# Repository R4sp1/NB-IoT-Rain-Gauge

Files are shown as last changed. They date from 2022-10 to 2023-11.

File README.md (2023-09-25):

# Návrh přesného srážkoměru s možností real-time odečtu

## Zadání
V teoretické části prostudujte principy měření objemu srážek. Prostudujte současné možnosti využití LPWAN sítí pro přenos naměřených hodnot. Na základě průzkumu dostupných řešení vyberte vhodnou metodu a měřicí modul pro přesné stanovení míry srážek. Současně vyberte vhodné komunikační řešení, které umožní real-time přenos naměřených hodnot. Výstupem semestrální práce je návrh a sestrojení zařízení pro přesné měření srážek s možností odesílání naměřených hodnot na server v reálném čase.

[Odkaz na práci](https://www.vut.cz/studenti/zav-prace/detail/151055 "Záverečné práce na VUT")

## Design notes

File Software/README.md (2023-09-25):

# Software folder
This folder contains all software:

* Firmware: contains two versions:
    * WiFi - using ESP32 onboard WiFi,
    * NB - using Quectel BC660K communication chip.
* Server-side: contains NodeRED flow which processes the data and sends them to the external InfluxDB database.

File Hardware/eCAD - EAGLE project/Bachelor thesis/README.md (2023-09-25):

# eCAD files
This subfolder contains project files from EAGLE eCAD software. The main design is located in folder: [Main board](https://github.com/R4sp1/NB-IoT-Rain-Gauge/tree/main/Hardware/eCAD%20-%20EAGLE%20project/Bachelor%20thesis/Main%20board).

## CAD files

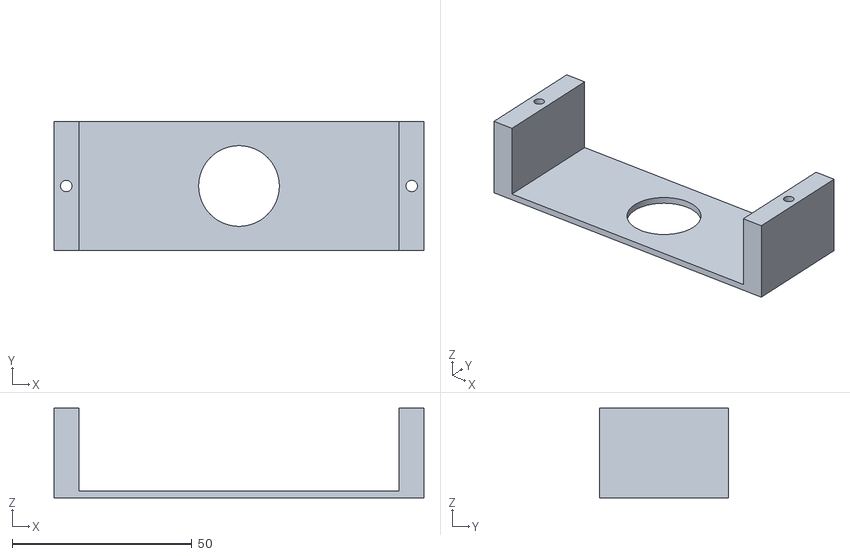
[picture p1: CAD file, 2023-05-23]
Hardware/Manufacture files/STL/Box/Cover.stl
102.8 x 35.8 x 25.0

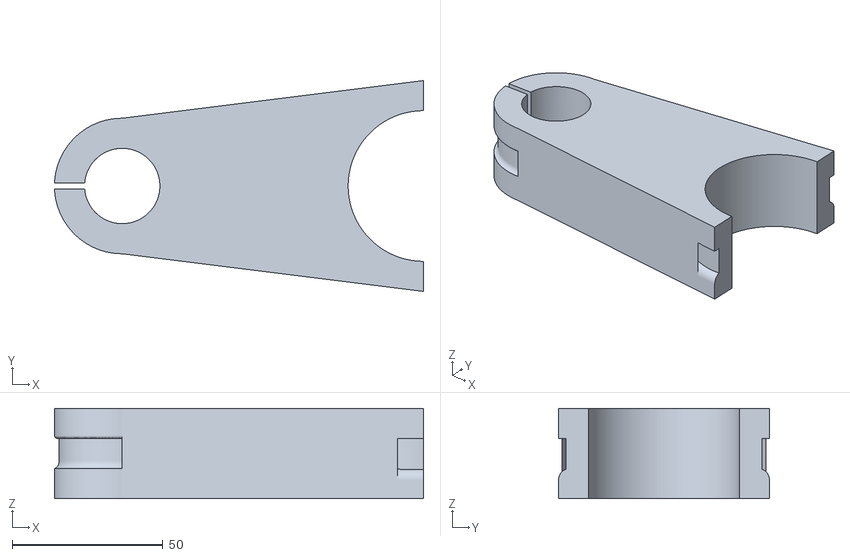
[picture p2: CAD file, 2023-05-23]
Hardware/Manufacture files/STL/Mount/Pole mount (50mm).stl
122.5 x 70.0 x 30.0

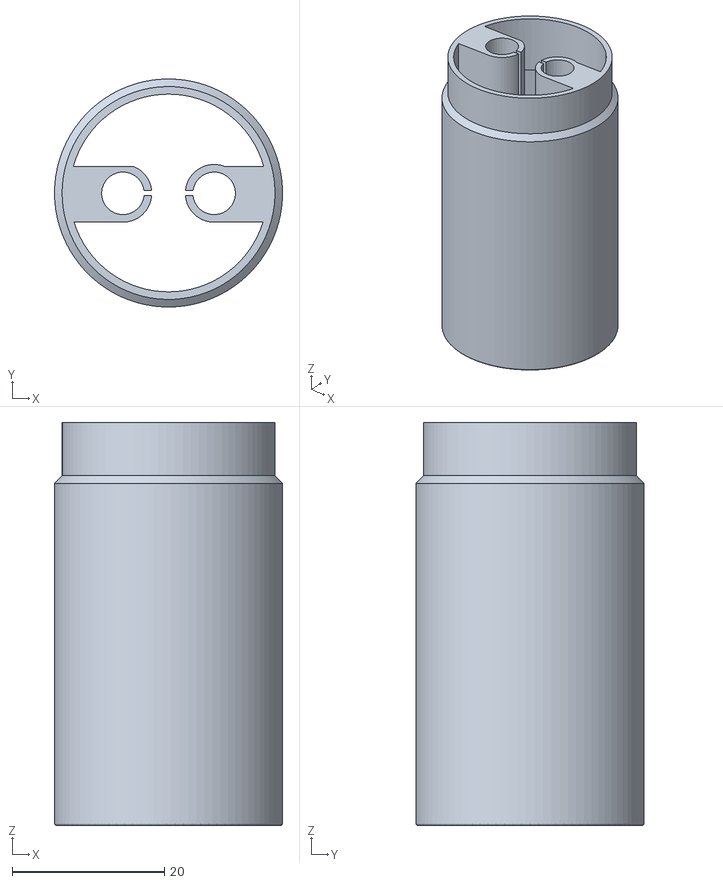
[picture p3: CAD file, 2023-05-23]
Hardware/Manufacture files/STL/Radiation shield/Bottom fan tube (temp sensor holders).stl
30.0 x 30.0 x 53.0

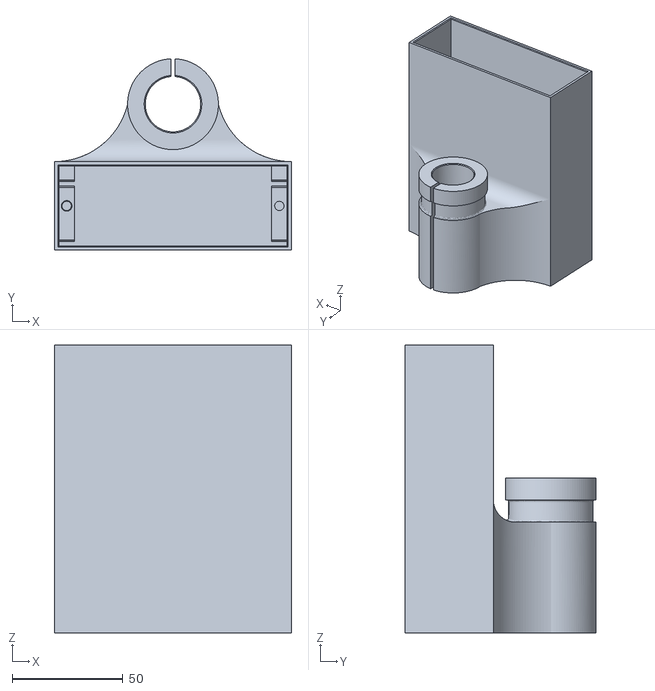
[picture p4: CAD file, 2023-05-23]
Hardware/Manufacture files/STL/Box/Box.stl
107.0 x 86.4 x 130.0

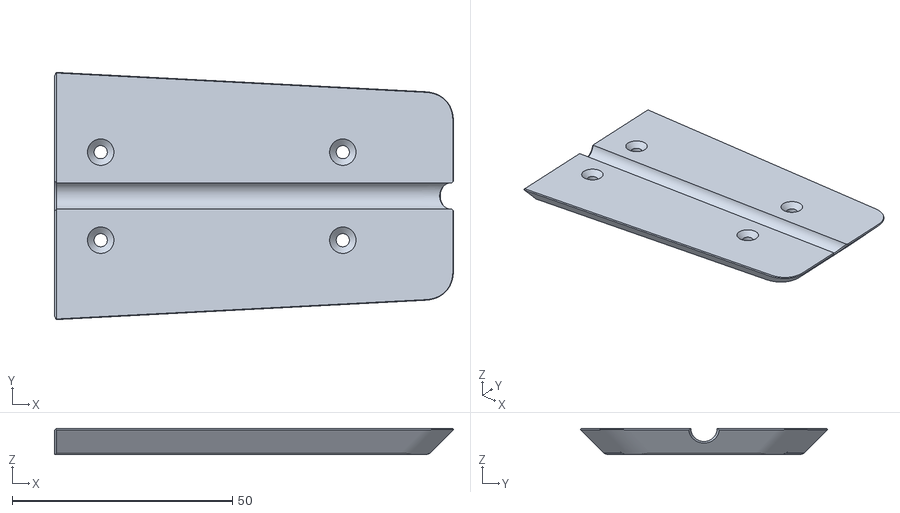
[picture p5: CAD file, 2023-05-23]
Hardware/Manufacture files/STL/Radiation shield/PV panel holder 2.stl
90.6 x 56.2 x 6.00

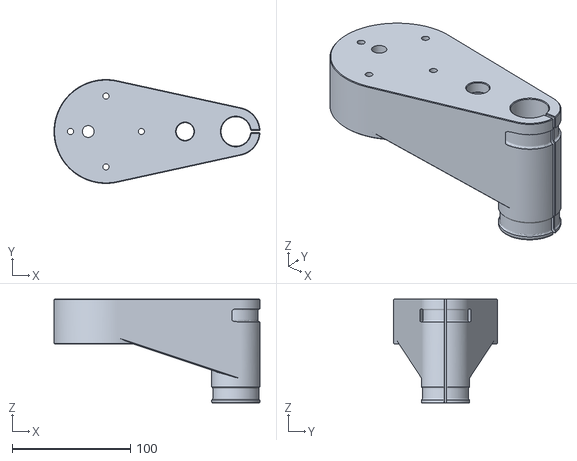
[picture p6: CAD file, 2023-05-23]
Hardware/Manufacture files/STL/Radiation shield/25mm pole mount.stl
174.5 x 88.0 x 88.0

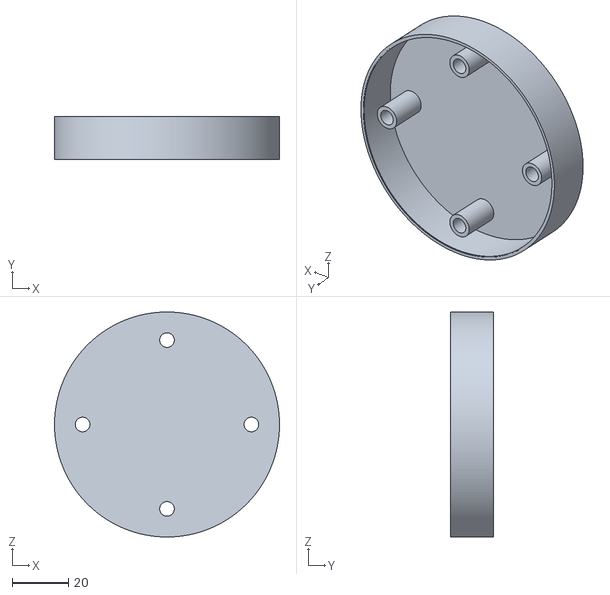
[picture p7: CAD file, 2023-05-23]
Hardware/Manufacture files/STL/Radiation shield/Fan cover.stl
80.0 x 15.2 x 80.0

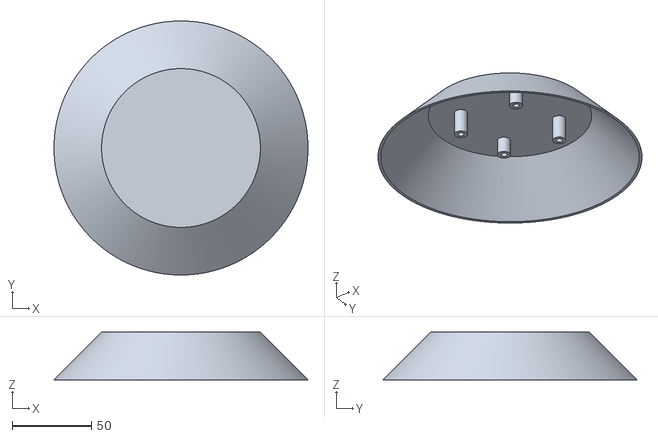
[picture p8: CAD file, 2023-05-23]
Hardware/Manufacture files/STL/Radiation shield/Top cover.stl
160.0 x 160.0 x 30.0

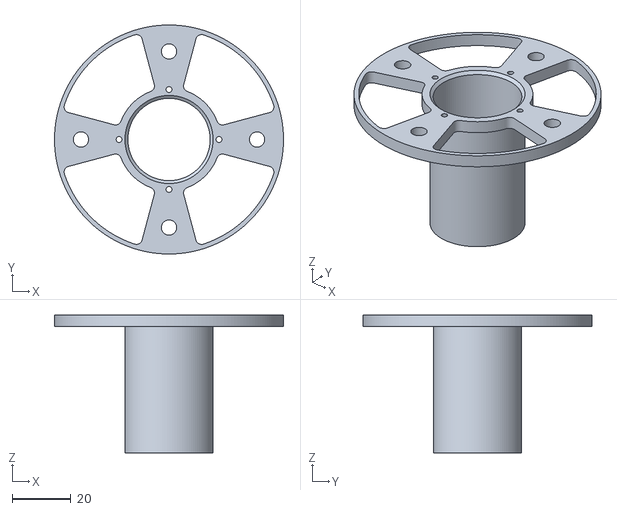
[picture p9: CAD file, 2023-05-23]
Hardware/Manufacture files/STL/Radiation shield/Top fan tube.stl
78.0 x 78.0 x 47.0

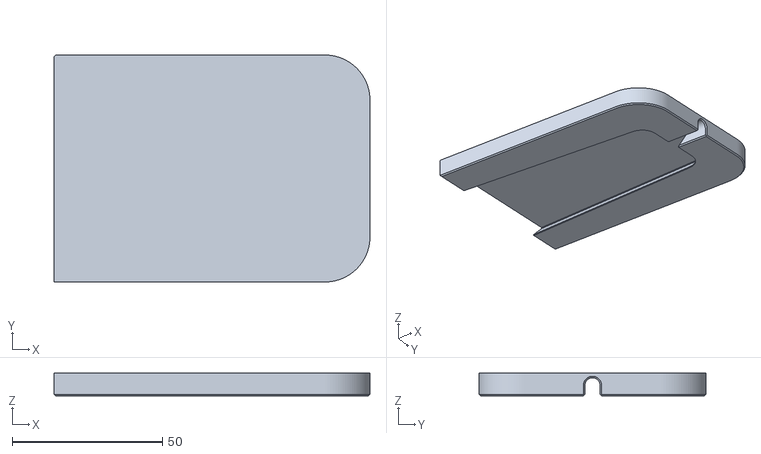
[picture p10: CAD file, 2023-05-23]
Hardware/Manufacture files/STL/Radiation shield/PV panel holder 3.stl
105.0 x 75.4 x 7.50

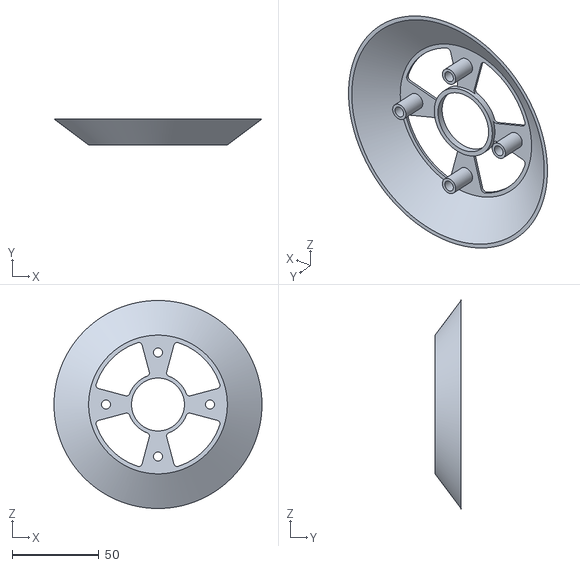
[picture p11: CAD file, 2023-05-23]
Hardware/Manufacture files/STL/Radiation shield/Shield.stl
120.0 x 15.0 x 120.0

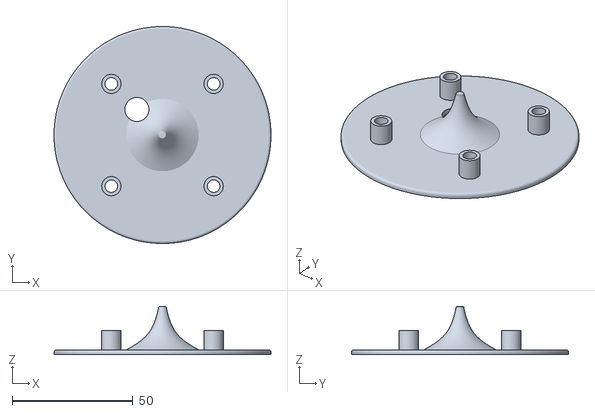
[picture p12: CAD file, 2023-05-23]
Hardware/Manufacture files/STL/Radiation shield/Bottom cover.stl
90.0 x 90.0 x 20.0

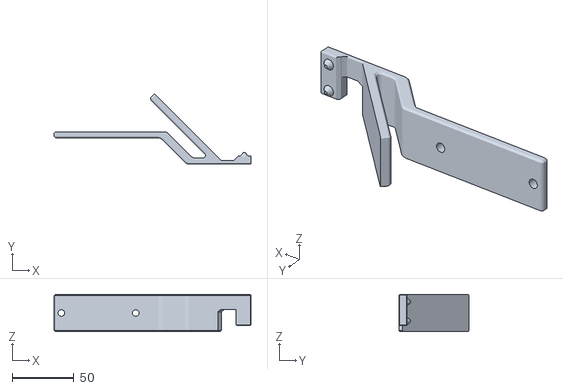
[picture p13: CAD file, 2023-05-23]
Hardware/Manufacture files/STL/Radiation shield/PV panel holder 1.stl
159.1 x 56.9 x 30.0

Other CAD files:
Hardware/CAD - Fusion360 3D models/Electronics box/Cover.f3d
Hardware/CAD - Fusion360 3D models/Electronics box/Electronics box.f3d
Hardware/CAD - Fusion360 3D models/Mount/Pole mount (50mm).f3d
Hardware/CAD - Fusion360 3D models/Radiation shield/Bottom cover.f3d
Hardware/CAD - Fusion360 3D models/Radiation shield/Bottom fan tube (temp sensor holders).f3d
Hardware/CAD - Fusion360 3D models/Radiation shield/Fan cover.f3d
Hardware/CAD - Fusion360 3D models/Radiation shield/Mount.f3d
Hardware/CAD - Fusion360 3D models/Radiation shield/PV panel holder 1.f3d
Hardware/CAD - Fusion360 3D models/Radiation shield/PV panel holder 2.f3d
Hardware/CAD - Fusion360 3D models/Radiation shield/PV panel holder 3.f3d
Hardware/CAD - Fusion360 3D models/Radiation shield/Shield.f3d
Hardware/CAD - Fusion360 3D models/Radiation shield/Top cover.f3d
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

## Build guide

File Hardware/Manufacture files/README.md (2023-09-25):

# Manufacture files
This subfolder contains files:

* ready to be printed as they are on Prusa i3 MK3S+,
* or files that can be imported into any slicer as .stl files.

RAW models in Fusion360 format .f3d can be found in [CAD - Fusion360 3D models](https://github.com/R4sp1/NB-IoT-Rain-Gauge/tree/main/Hardware/CAD%20-%20Fusion360%203D%20models) folder.

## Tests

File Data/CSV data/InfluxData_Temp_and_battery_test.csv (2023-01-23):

#group | false | false | true | true | false | false | true | true
#datatype | string | long | dateTime:RFC3339 | dateTime:RFC3339 | dateTime:RFC3339 | double | string | string
#default | last
 | result | table | _start | _stop | _time | _value | _field | _measurement
 |  | 0 | 2022-12-25T16:00:00Z | 2023-01-09T13:00:00Z | 2022-12-25T16:08:30Z | 6.125 | Temp | NBtest
 |  | 0 | 2022-12-25T16:00:00Z | 2023-01-09T13:00:00Z | 2022-12-25T17:08:00Z | 4.1875 | Temp | NBtest
 |  | 0 | 2022-12-25T16:00:00Z | 2023-01-09T13:00:00Z | 2022-12-25T18:07:30Z | 3.375 | Temp | NBtest
 |  | 0 | 2022-12-25T16:00:00Z | 2023-01-09T13:00:00Z | 2022-12-25T19:07:00Z | 3.25 | Temp | NBtest
 |  | 0 | 2022-12-25T16:00:00Z | 2023-01-09T13:00:00Z | 2022-12-25T20:06:30Z | 3.5 | Temp | NBtest
 |  | 0 | 2022-12-25T16:00:00Z | 2023-01-09T13:00:00Z | 2022-12-25T21:06:00Z | 4 | Temp | NBtest
 |  | 0 | 2022-12-25T16:00:00Z | 2023-01-09T13:00:00Z | 2022-12-25T22:05:30Z | 3.3125 | Temp | NBtest
 |  | 0 | 2022-12-25T16:00:00Z | 2023-01-09T13:00:00Z | 2022-12-25T23:05:00Z | 3.125 | Temp | NBtest
 |  | 0 | 2022-12-25T16:00:00Z | 2023-01-09T13:00:00Z | 2022-12-26T00:04:30Z | 2.625 | Temp | NBtest
 |  | 0 | 2022-12-25T16:00:00Z | 2023-01-09T13:00:00Z | 2022-12-26T01:04:00Z | 6.5625 | Temp | NBtest
 |  | 0 | 2022-12-25T16:00:00Z | 2023-01-09T13:00:00Z | 2022-12-26T02:03:30Z | 5.375 | Temp | NBtest
 |  | 0 | 2022-12-25T16:00:00Z | 2023-01-09T13:00:00Z | 2022-12-26T03:03:00Z | 4.625 | Temp | NBtest
 |  | 0 | 2022-12-25T16:00:00Z | 2023-01-09T13:00:00Z | 2022-12-26T04:02:30Z | 3.75 | Temp | NBtest
 |  | 0 | 2022-12-25T16:00:00Z | 2023-01-09T13:00:00Z | 2022-12-26T05:02:00Z | 2.5 | Temp | NBtest
 |  | 0 | 2022-12-25T16:00:00Z | 2023-01-09T13:00:00Z | 2022-12-26T06:01:30Z | 1.5625 | Temp | NBtest
 |  | 0 | 2022-12-25T16:00:00Z | 2023-01-09T13:00:00Z | 2022-12-26T07:01:00Z | 1.5 | Temp | NBtest
 |  | 0 | 2022-12-25T16:00:00Z | 2023-01-09T13:00:00Z | 2022-12-26T08:00:30Z | 1.6875 | Temp | NBtest
 |  | 0 | 2022-12-25T16:00:00Z | 2023-01-09T13:00:00Z | 2022-12-26T09:00:00Z | 3.6875 | Temp | NBtest
 |  | 0 | 2022-12-25T16:00:00Z | 2023-01-09T13:00:00Z | 2022-12-26T09:59:30Z | 7.9375 | Temp | NBtest
 |  | 0 | 2022-12-25T16:00:00Z | 2023-01-09T13:00:00Z | 2022-12-26T10:59:00Z | 11.125 | Temp | NBtest
 |  | 0 | 2022-12-25T16:00:00Z | 2023-01-09T13:00:00Z | 2022-12-26T11:58:30Z | 11.4375 | Temp | NBtest
 |  | 0 | 2022-12-25T16:00:00Z | 2023-01-09T13:00:00Z | 2022-12-26T12:58:00Z | 11.125 | Temp | NBtest
 |  | 0 | 2022-12-25T16:00:00Z | 2023-01-09T13:00:00Z | 2022-12-26T13:57:30Z | 11.125 | Temp | NBtest
 |  | 0 | 2022-12-25T16:00:00Z | 2023-01-09T13:00:00Z | 2022-12-26T14:57:00Z | 9.625 | Temp | NBtest
 |  | 0 | 2022-12-25T16:00:00Z | 2023-01-09T13:00:00Z | 2022-12-26T15:56:30Z | 8.6875 | Temp | NBtest
 |  | 0 | 2022-12-25T16:00:00Z | 2023-01-09T13:00:00Z | 2022-12-26T16:56:00Z | 8.625 | Temp | NBtest
 |  | 0 | 2022-12-25T16:00:00Z | 2023-01-09T13:00:00Z | 2022-12-26T17:55:30Z | 8.6875 | Temp | NBtest
 |  | 0 | 2022-12-25T16:00:00Z | 2023-01-09T13:00:00Z | 2022-12-26T18:55:00Z | 8.625 | Temp | NBtest
 |  | 0 | 2022-12-25T16:00:00Z | 2023-01-09T13:00:00Z | 2022-12-26T19:54:30Z | 8.5625 | Temp | NBtest
 |  | 0 | 2022-12-25T16:00:00Z | 2023-01-09T13:00:00Z | 2022-12-26T20:54:00Z | 8.3125 | Temp | NBtest
 |  | 0 | 2022-12-25T16:00:00Z | 2023-01-09T13:00:00Z | 2022-12-26T21:53:30Z | 8.1875 | Temp | NBtest
 |  | 0 | 2022-12-25T16:00:00Z | 2023-01-09T13:00:00Z | 2022-12-26T22:53:00Z | 7.9375 | Temp | NBtest
 |  | 0 | 2022-12-25T16:00:00Z | 2023-01-09T13:00:00Z | 2022-12-26T23:52:30Z | 7.3125 | Temp | NBtest
 |  | 0 | 2022-12-25T16:00:00Z | 2023-01-09T13:00:00Z | 2022-12-27T00:52:00Z | 7.0625 | Temp | NBtest
 |  | 0 | 2022-12-25T16:00:00Z | 2023-01-09T13:00:00Z | 2022-12-27T01:51:30Z | 6.625 | Temp | NBtest
 |  | 0 | 2022-12-25T16:00:00Z | 2023-01-09T13:00:00Z | 2022-12-27T02:51:00Z | 5.75 | Temp | NBtest
 |  | 0 | 2022-12-25T16:00:00Z | 2023-01-09T13:00:00Z | 2022-12-27T03:50:30Z | 4.75 | Temp | NBtest
 |  | 0 | 2022-12-25T16:00:00Z | 2023-01-09T13:00:00Z | 2022-12-27T04:50:00Z | 2.8125 | Temp | NBtest
 |  | 0 | 2022-12-25T16:00:00Z | 2023-01-09T13:00:00Z | 2022-12-27T05:49:30Z | 1.5 | Temp | NBtest
 |  | 0 | 2022-12-25T16:00:00Z | 2023-01-09T13:00:00Z | 2022-12-27T06:49:00Z | 1.125 | Temp | NBtest
 |  | 0 | 2022-12-25T16:00:00Z | 2023-01-09T13:00:00Z | 2022-12-27T07:48:30Z | 0.5625 | Temp | NBtest
 |  | 0 | 2022-12-25T16:00:00Z | 2023-01-09T13:00:00Z | 2022-12-27T08:48:00Z | 1.875 | Temp | NBtest
 |  | 0 | 2022-12-25T16:00:00Z | 2023-01-09T13:00:00Z | 2022-12-27T09:47:30Z | 3.3125 | Temp | NBtest
 |  | 0 | 2022-12-25T16:00:00Z | 2023-01-09T13:00:00Z | 2022-12-27T10:47:00Z | 4.5625 | Temp | NBtest
 |  | 0 | 2022-12-25T16:00:00Z | 2023-01-09T13:00:00Z | 2022-12-27T11:46:30Z | 4.9375 | Temp | NBtest
 |  | 0 | 2022-12-25T16:00:00Z | 2023-01-09T13:00:00Z | 2022-12-27T12:46:00Z | 4.4375 | Temp | NBtest
 |  | 0 | 2022-12-25T16:00:00Z | 2023-01-09T13:00:00Z | 2022-12-27T13:45:30Z | 4.625 | Temp | NBtest
 |  | 0 | 2022-12-25T16:00:00Z | 2023-01-09T13:00:00Z | 2022-12-27T14:45:00Z | 3.6875 | Temp | NBtest
 |  | 0 | 2022-12-25T16:00:00Z | 2023-01-09T13:00:00Z | 2022-12-27T15:44:30Z | 2.625 | Temp | NBtest
 |  | 0 | 2022-12-25T16:00:00Z | 2023-01-09T13:00:00Z | 2022-12-27T16:44:00Z | 1.0625 | Temp | NBtest
 |  | 0 | 2022-12-25T16:00:00Z | 2023-01-09T13:00:00Z | 2022-12-27T17:43:30Z | 0.3125 | Temp | NBtest
 |  | 0 | 2022-12-25T16:00:00Z | 2023-01-09T13:00:00Z | 2022-12-27T18:43:00Z | -0.1875 | Temp | NBtest
 |  | 0 | 2022-12-25T16:00:00Z | 2023-01-09T13:00:00Z | 2022-12-27T19:42:30Z | 1.125 | Temp | NBtest
 |  | 0 | 2022-12-25T16:00:00Z | 2023-01-09T13:00:00Z | 2022-12-27T20:42:00Z | 0.3125 | Temp | NBtest
 |  | 0 | 2022-12-25T16:00:00Z | 2023-01-09T13:00:00Z | 2022-12-27T21:41:30Z | -0.625 | Temp | NBtest
 |  | 0 | 2022-12-25T16:00:00Z | 2023-01-09T13:00:00Z | 2022-12-27T22:41:00Z | -1.5 | Temp | NBtest
 |  | 0 | 2022-12-25T16:00:00Z | 2023-01-09T13:00:00Z | 2022-12-27T23:40:30Z | -2.25 | Temp | NBtest
 |  | 0 | 2022-12-25T16:00:00Z | 2023-01-09T13:00:00Z | 2022-12-28T00:40:00Z | -3 | Temp | NBtest
 |  | 0 | 2022-12-25T16:00:00Z | 2023-01-09T13:00:00Z | 2022-12-28T01:39:30Z | -3.3125 | Temp | NBtest
 |  | 0 | 2022-12-25T16:00:00Z | 2023-01-09T13:00:00Z | 2022-12-28T02:39:00Z | -3.9375 | Temp | NBtest
 |  | 0 | 2022-12-25T16:00:00Z | 2023-01-09T13:00:00Z | 2022-12-28T03:38:30Z | -4.125 | Temp | NBtest
 |  | 0 | 2022-12-25T16:00:00Z | 2023-01-09T13:00:00Z | 2022-12-28T04:38:00Z | -4.5 | Temp | NBtest
 |  | 0 | 2022-12-25T16:00:00Z | 2023-01-09T13:00:00Z | 2022-12-28T05:37:30Z | -3.5625 | Temp | NBtest
 |  | 0 | 2022-12-25T16:00:00Z | 2023-01-09T13:00:00Z | 2022-12-28T06:37:00Z | -3 | Temp | NBtest
 |  | 0 | 2022-12-25T16:00:00Z | 2023-01-09T13:00:00Z | 2022-12-28T07:36:30Z | -2.0625 | Temp | NBtest
 |  | 0 | 2022-12-25T16:00:00Z | 2023-01-09T13:00:00Z | 2022-12-28T08:36:00Z | 1.3125 | Temp | NBtest
 |  | 0 | 2022-12-25T16:00:00Z | 2023-01-09T13:00:00Z | 2022-12-28T09:35:30Z | 2.625 | Temp | NBtest
 |  | 0 | 2022-12-25T16:00:00Z | 2023-01-09T13:00:00Z | 2022-12-28T10:35:00Z | 3.875 | Temp | NBtest
 |  | 0 | 2022-12-25T16:00:00Z | 2023-01-09T13:00:00Z | 2022-12-28T11:34:30Z | 5.25 | Temp | NBtest
 |  | 0 | 2022-12-25T16:00:00Z | 2023-01-09T13:00:00Z | 2022-12-28T12:34:00Z | 5.375 | Temp | NBtest
 |  | 0 | 2022-12-25T16:00:00Z | 2023-01-09T13:00:00Z | 2022-12-28T13:33:30Z | 4.9375 | Temp | NBtest
 |  | 0 | 2022-12-25T16:00:00Z | 2023-01-09T13:00:00Z | 2022-12-28T14:33:00Z | 5.5625 | Temp | NBtest
 |  | 0 | 2022-12-25T16:00:00Z | 2023-01-09T13:00:00Z | 2022-12-28T15:32:30Z | 5 | Temp | NBtest
 |  | 0 | 2022-12-25T16:00:00Z | 2023-01-09T13:00:00Z | 2022-12-28T16:32:00Z | 4.0625 | Temp | NBtest
 |  | 0 | 2022-12-25T16:00:00Z | 2023-01-09T13:00:00Z | 2022-12-28T17:31:30Z | 3.875 | Temp | NBtest
 |  | 0 | 2022-12-25T16:00:00Z | 2023-01-09T13:00:00Z | 2022-12-28T18:31:00Z | 4.5 | Temp | NBtest
 |  | 0 | 2022-12-25T16:00:00Z | 2023-01-09T13:00:00Z | 2022-12-28T19:30:30Z | 4.125 | Temp | NBtest
 |  | 0 | 2022-12-25T16:00:00Z | 2023-01-09T13:00:00Z | 2022-12-28T20:30:00Z | 3.5625 | Temp | NBtest
 |  | 0 | 2022-12-25T16:00:00Z | 2023-01-09T13:00:00Z | 2022-12-28T21:29:30Z | 3.25 | Temp | NBtest
 |  | 0 | 2022-12-25T16:00:00Z | 2023-01-09T13:00:00Z | 2022-12-28T22:29:00Z | 3.875 | Temp | NBtest
 |  | 0 | 2022-12-25T16:00:00Z | 2023-01-09T13:00:00Z | 2022-12-28T23:28:30Z | 4.375 | Temp | NBtest
 |  | 0 | 2022-12-25T16:00:00Z | 2023-01-09T13:00:00Z | 2022-12-29T00:28:00Z | 2.5 | Temp | NBtest
 |  | 0 | 2022-12-25T16:00:00Z | 2023-01-09T13:00:00Z | 2022-12-29T01:27:30Z | 1.75 | Temp | NBtest
 |  | 0 | 2022-12-25T16:00:00Z | 2023-01-09T13:00:00Z | 2022-12-29T02:27:00Z | 0.875 | Temp | NBtest
 |  | 0 | 2022-12-25T16:00:00Z | 2023-01-09T13:00:00Z | 2022-12-29T03:26:30Z | 0.6875 | Temp | NBtest
 |  | 0 | 2022-12-25T16:00:00Z | 2023-01-09T13:00:00Z | 2022-12-29T04:26:00Z | 0.625 | Temp | NBtest
 |  | 0 | 2022-12-25T16:00:00Z | 2023-01-09T13:00:00Z | 2022-12-29T05:25:30Z | 1.625 | Temp | NBtest
 |  | 0 | 2022-12-25T16:00:00Z | 2023-01-09T13:00:00Z | 2022-12-29T06:25:00Z | 2.25 | Temp | NBtest
 |  | 0 | 2022-12-25T16:00:00Z | 2023-01-09T13:00:00Z | 2022-12-29T07:24:30Z | 3.8125 | Temp | NBtest
 |  | 0 | 2022-12-25T16:00:00Z | 2023-01-09T13:00:00Z | 2022-12-29T08:24:00Z | 5.25 | Temp | NBtest
 |  | 0 | 2022-12-25T16:00:00Z | 2023-01-09T13:00:00Z | 2022-12-29T09:23:30Z | 12.0625 | Temp | NBtest
 |  | 0 | 2022-12-25T16:00:00Z | 2023-01-09T13:00:00Z | 2022-12-29T10:23:00Z | 12.25 | Temp | NBtest
 |  | 0 | 2022-12-25T16:00:00Z | 2023-01-09T13:00:00Z | 2022-12-29T11:22:30Z | 12.375 | Temp | NBtest
 |  | 0 | 2022-12-25T16:00:00Z | 2023-01-09T13:00:00Z | 2022-12-29T12:22:00Z | 12.9375 | Temp | NBtest
 |  | 0 | 2022-12-25T16:00:00Z | 2023-01-09T13:00:00Z | 2022-12-29T13:21:30Z | 13.25 | Temp | NBtest
 |  | 0 | 2022-12-25T16:00:00Z | 2023-01-09T13:00:00Z | 2022-12-29T14:21:00Z | 11.125 | Temp | NBtest
 |  | 0 | 2022-12-25T16:00:00Z | 2023-01-09T13:00:00Z | 2022-12-29T15:20:30Z | 9.5 | Temp | NBtest
 |  | 0 | 2022-12-25T16:00:00Z | 2023-01-09T13:00:00Z | 2022-12-29T16:20:00Z | 8.6875 | Temp | NBtest
 |  | 0 | 2022-12-25T16:00:00Z | 2023-01-09T13:00:00Z | 2022-12-29T17:19:30Z | 8.0625 | Temp | NBtest
 |  | 0 | 2022-12-25T16:00:00Z | 2023-01-09T13:00:00Z | 2022-12-29T18:19:00Z | 6.9375 | Temp | NBtest
 |  | 0 | 2022-12-25T16:00:00Z | 2023-01-09T13:00:00Z | 2022-12-29T19:18:30Z | 4.625 | Temp | NBtest
 |  | 0 | 2022-12-25T16:00:00Z | 2023-01-09T13:00:00Z | 2022-12-29T20:18:00Z | 6.1875 | Temp | NBtest
 |  | 0 | 2022-12-25T16:00:00Z | 2023-01-09T13:00:00Z | 2022-12-29T21:17:30Z | 3.5 | Temp | NBtest
 |  | 0 | 2022-12-25T16:00:00Z | 2023-01-09T13:00:00Z | 2022-12-29T22:17:00Z | 2.3125 | Temp | NBtest
 |  | 0 | 2022-12-25T16:00:00Z | 2023-01-09T13:00:00Z | 2022-12-29T23:16:30Z | 1.5625 | Temp | NBtest
 |  | 0 | 2022-12-25T16:00:00Z | 2023-01-09T13:00:00Z | 2022-12-30T00:16:00Z | 1.625 | Temp | NBtest
 |  | 0 | 2022-12-25T16:00:00Z | 2023-01-09T13:00:00Z | 2022-12-30T01:15:30Z | 1.0625 | Temp | NBtest
 |  | 0 | 2022-12-25T16:00:00Z | 2023-01-09T13:00:00Z | 2022-12-30T02:15:00Z | 1.375 | Temp | NBtest
 |  | 0 | 2022-12-25T16:00:00Z | 2023-01-09T13:00:00Z | 2022-12-30T03:14:30Z | 2.125 | Temp | NBtest
 |  | 0 | 2022-12-25T16:00:00Z | 2023-01-09T13:00:00Z | 2022-12-30T04:14:00Z | 2.875 | Temp | NBtest
 |  | 0 | 2022-12-25T16:00:00Z | 2023-01-09T13:00:00Z | 2022-12-30T05:13:30Z | 4.1875 | Temp | NBtest
 |  | 0 | 2022-12-25T16:00:00Z | 2023-01-09T13:00:00Z | 2022-12-30T06:13:00Z | 3.875 | Temp | NBtest
 |  | 0 | 2022-12-25T16:00:00Z | 2023-01-09T13:00:00Z | 2022-12-30T07:12:30Z | 4.375 | Temp | NBtest
 |  | 0 | 2022-12-25T16:00:00Z | 2023-01-09T13:00:00Z | 2022-12-30T08:12:00Z | 4.625 | Temp | NBtest
 |  | 0 | 2022-12-25T16:00:00Z | 2023-01-09T13:00:00Z | 2022-12-30T09:11:30Z | 5.875 | Temp | NBtest
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

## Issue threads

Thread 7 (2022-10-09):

Temp sensors - type

R4sp1, 2022-10-09:

R4sp1, 2022-10-16:
Temp sensors will be present - need to chose right type of sensor

R4sp1, 2022-10-30:
Test of temp sensors in progress. Most likely will use DS18B.

R4sp1, 2022-11-06:
DS18B20 proved to be a good choice. Two connected sensors on 1-wire bus are showing good stability and their output is very close each to other. [Output in Grafana can be found here.](https://snapshots.raintank.io/dashboard/snapshot/5U4Xh7PnYINNakNIex6pqY97nyXPeeNc)

Closed 2022-11-06.

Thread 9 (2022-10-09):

MPPT

R4sp1, 2022-10-09:

R4sp1, 2022-10-18:
Actually almost doesn't matter when using small PV panels (6 V output) as shown and tested in these videos:
[#154 Solar Charger for Microcontrollers](https://www.youtube.com/watch?v=dBx-g1dkdDQ)
[#155 The 5 Best Solar ChargerBoards for Arduino and ESP8266 - (full sun comparison)](https://www.youtube.com/watch?v=ttyKZnVzic4&t=33s)

Closed 2022-10-18.

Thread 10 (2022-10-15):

TP4056 based charger

R4sp1, 2022-10-15:
- [x] Add power path
- [x] Sense pins for uControler for !CHRG and !STDBY signals
- [ ] NTC to monitor temperature on battery
- [ ] Sense pin to monitor voltage on TEMP signal (voltage devider)
- [x] Pin to monitor battery voltage (voltage devider)

R4sp1, 2022-11-06:
Currently test is in progress

R4sp1, 2022-11-13:
Added bigger 4.5W PV panel to the test.

Closed 2023-02-27.

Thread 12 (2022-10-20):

Temp sensor comparison (test them, compare their output in grafana)

R4sp1, 2022-10-20:
Do a test sensor which will measure temp with different temp sensors and send their value to grafana using MQTT
Possible to test a PV panel with TP4056 charger board

R4sp1, 2022-10-20:
Device is up and collecting data

R4sp1, 2022-11-06:
Closed in [#7 issue](https://github.com/R4sp1/bachelor-thesis/issues/7)

Closed 2022-11-06.

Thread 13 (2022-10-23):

Enclosure and radiation shield

R4sp1, 2022-10-23:
Radiation shield for temperature monitoring can be passive or active. In active solution there is a fan blowing air towards the sensors to reduce heat accumulation. Fan should be controlled through a MOSFET but should be on when there is no solar energy? We can take advantage of power path implementation and provide VCC to the fan only from there => if there is enough of solar intensity and MOSFET is open, fan will be spinning, if not fan will be off => actually we don't need a fan when there is no sun shining to the shiled and creating heat accumulation inside.

R4sp1, 2022-12-13:
Radiation shield done

R4sp1, 2023-05-23:
Done, files are in repo

Closed 2023-05-23.

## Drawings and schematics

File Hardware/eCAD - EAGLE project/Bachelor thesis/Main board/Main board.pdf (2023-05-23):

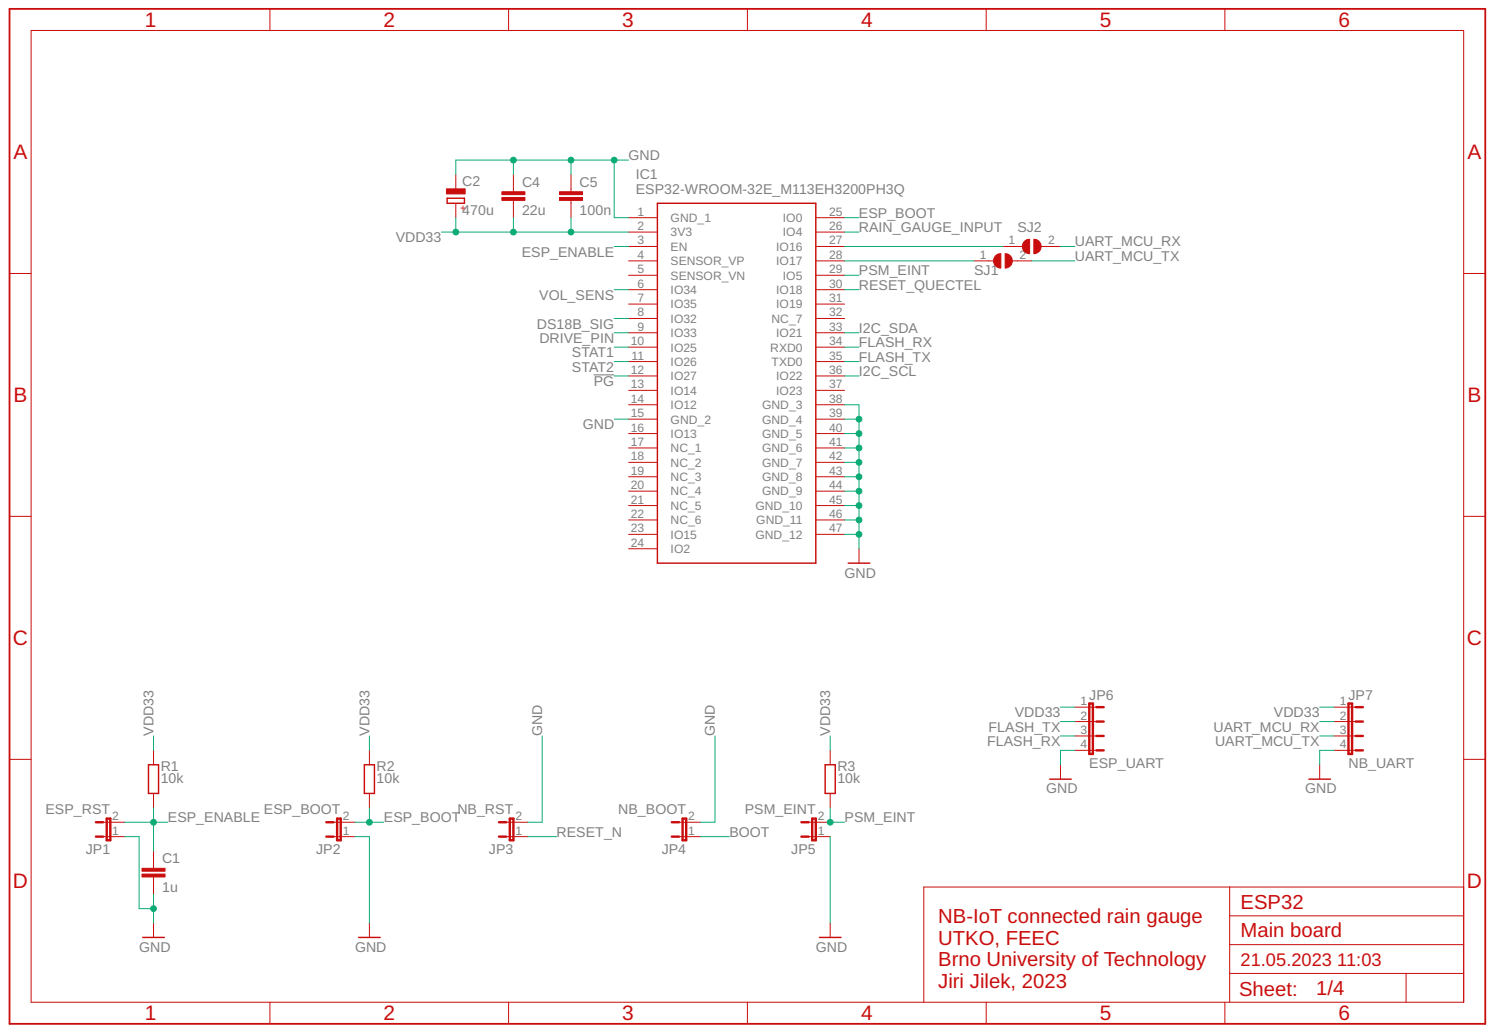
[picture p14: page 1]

NB-IoT connected rain gauge
UTKO, FEEC
Brno University of Technology

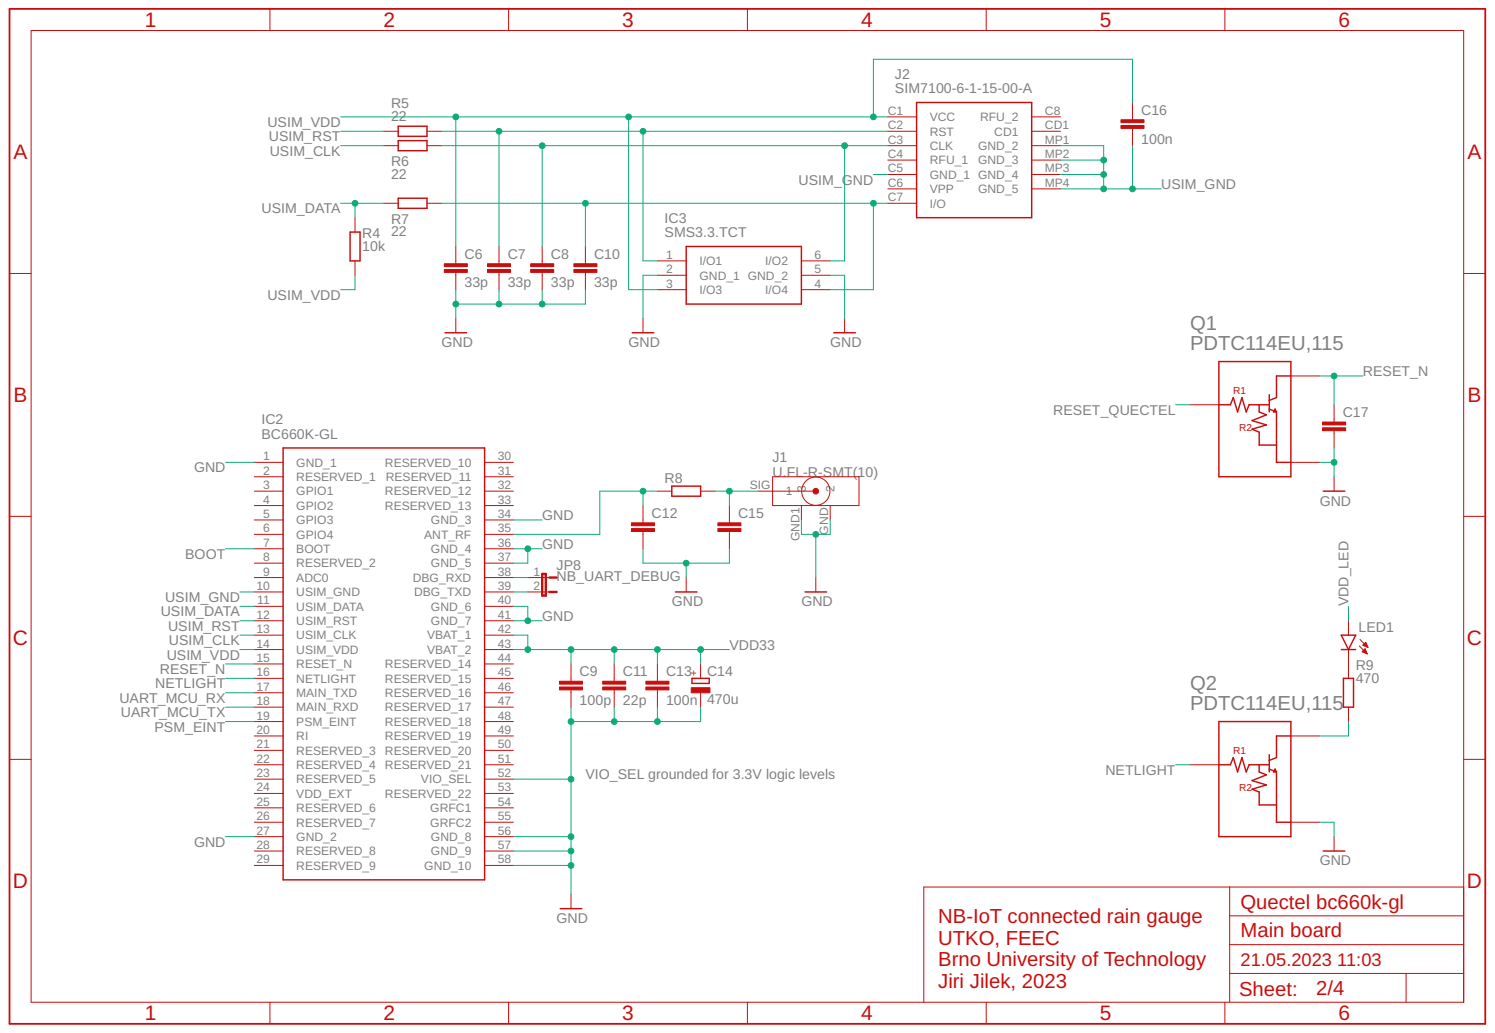
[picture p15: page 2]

PDTC114EU,115

VIO_SEL grounded for 3.3V logic levels

NB-IoT connected rain gauge UTKO, FEEC Brno University of Technology Jiri Jilek, 2023

Sheet: 2/4

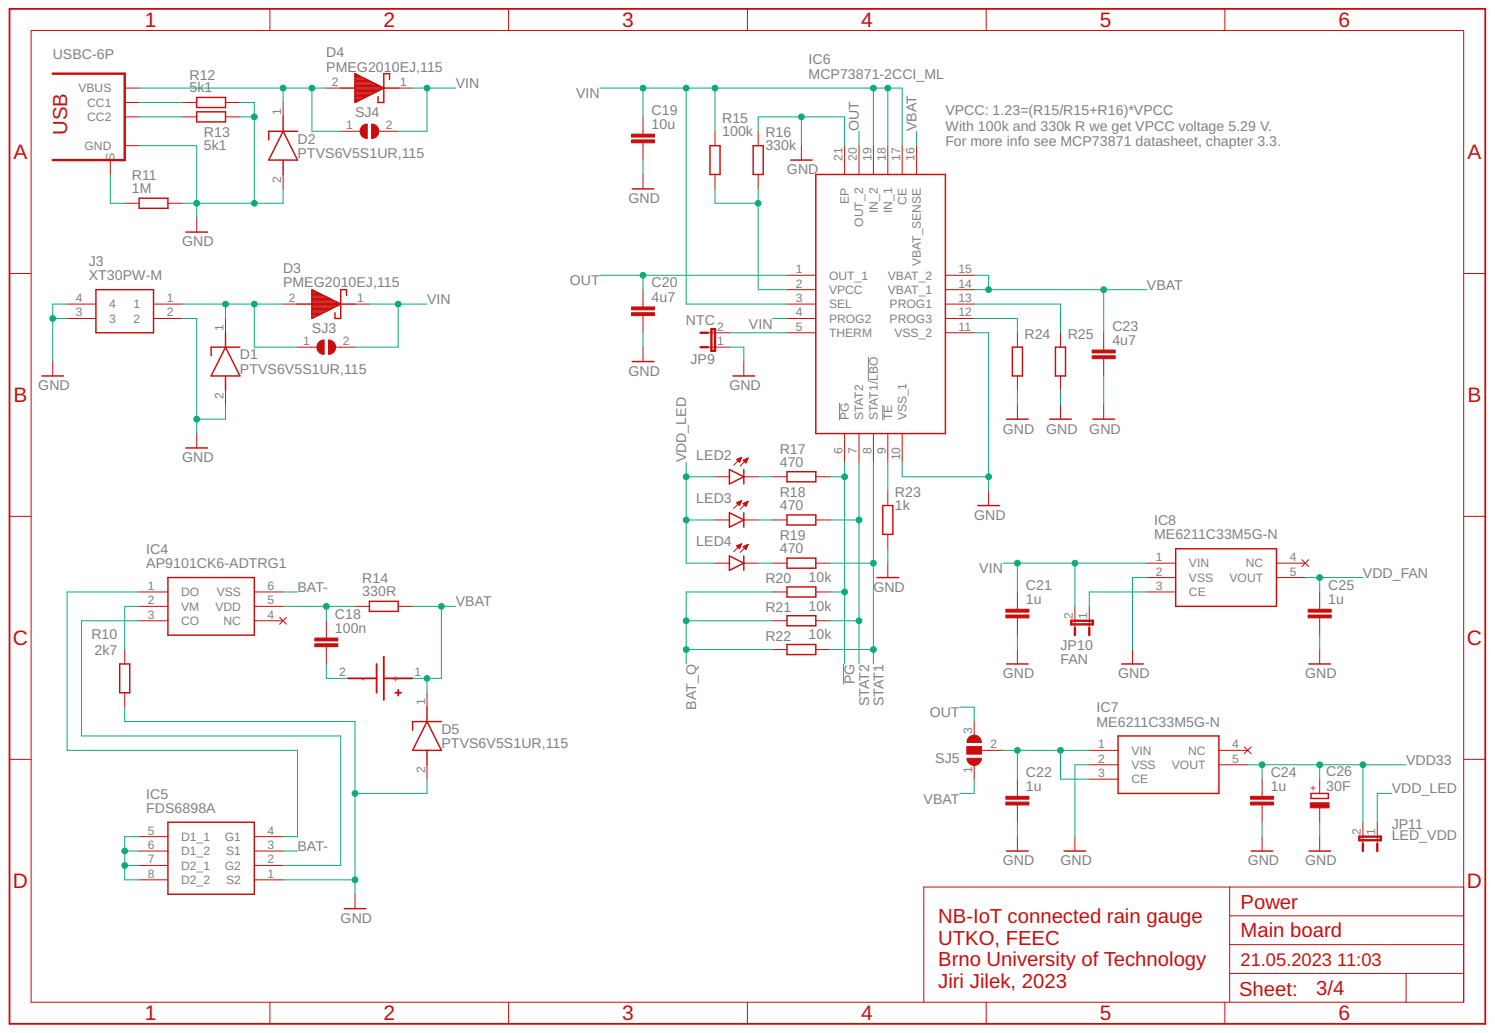
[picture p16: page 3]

VBAT
VPCC: 1.23=(R15/R15+R16)*VPCC
With 100k and 330k R we get VPCC voltage 5.29 V. For more info see MCP73871 datasheet, chapter 3.3.

NB-IoT connected rain gauge
UTKO, FEEC
Brno University of Technology

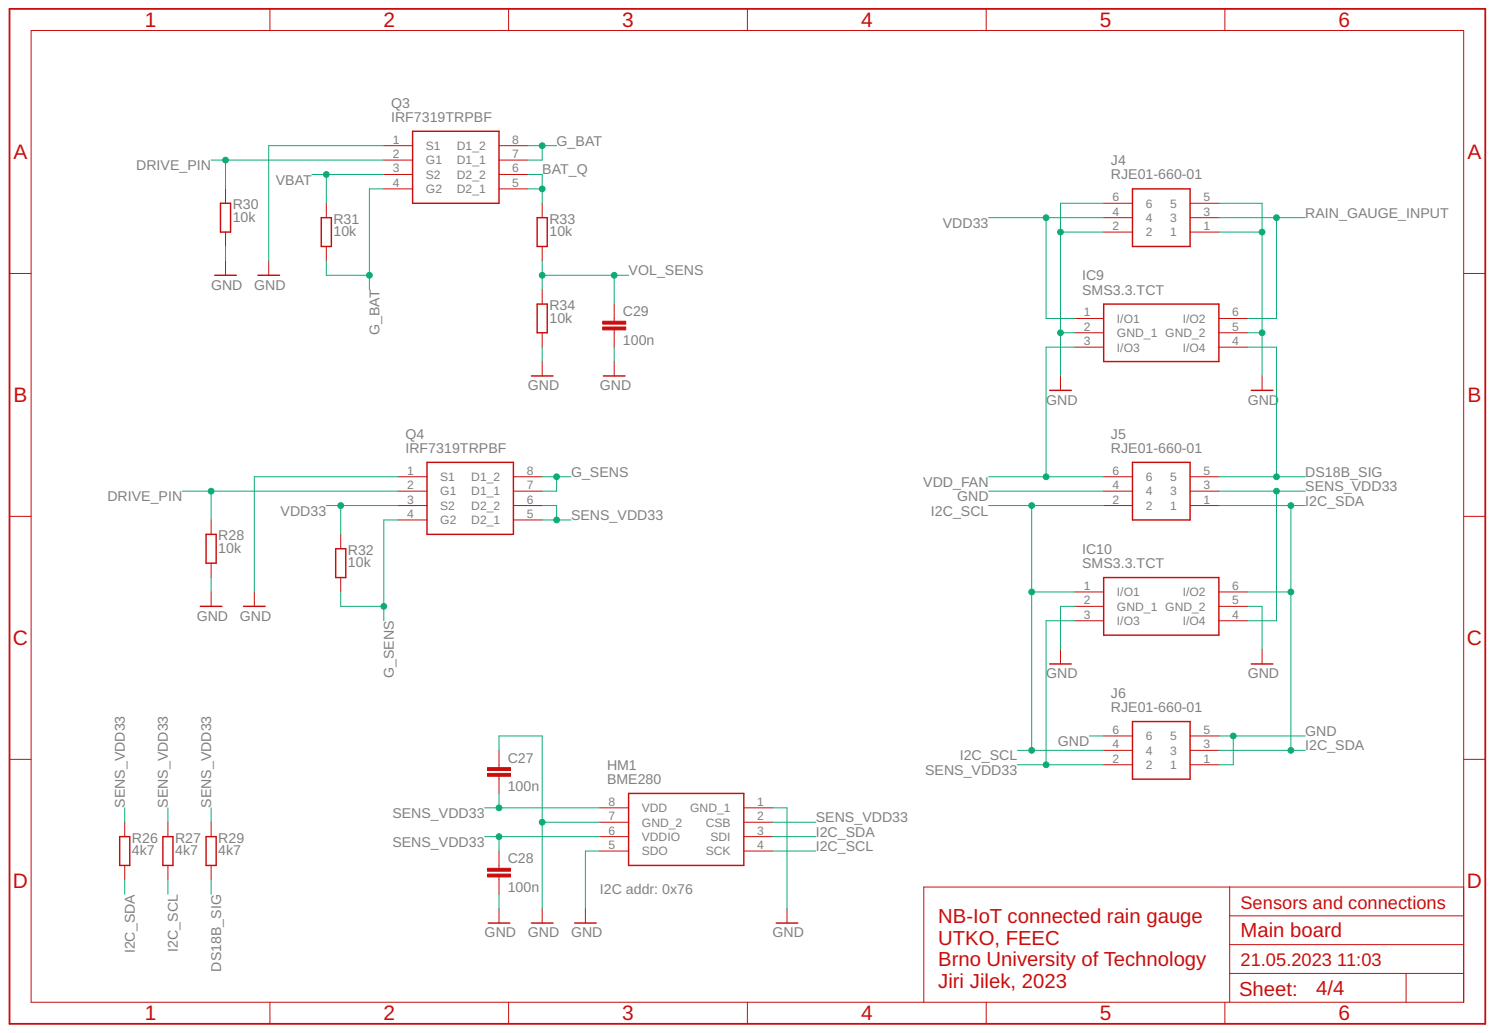
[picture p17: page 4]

4 | | 3 1

NB-IoT connected rain gauge
UTKO, FEEC
Brno University of Technology

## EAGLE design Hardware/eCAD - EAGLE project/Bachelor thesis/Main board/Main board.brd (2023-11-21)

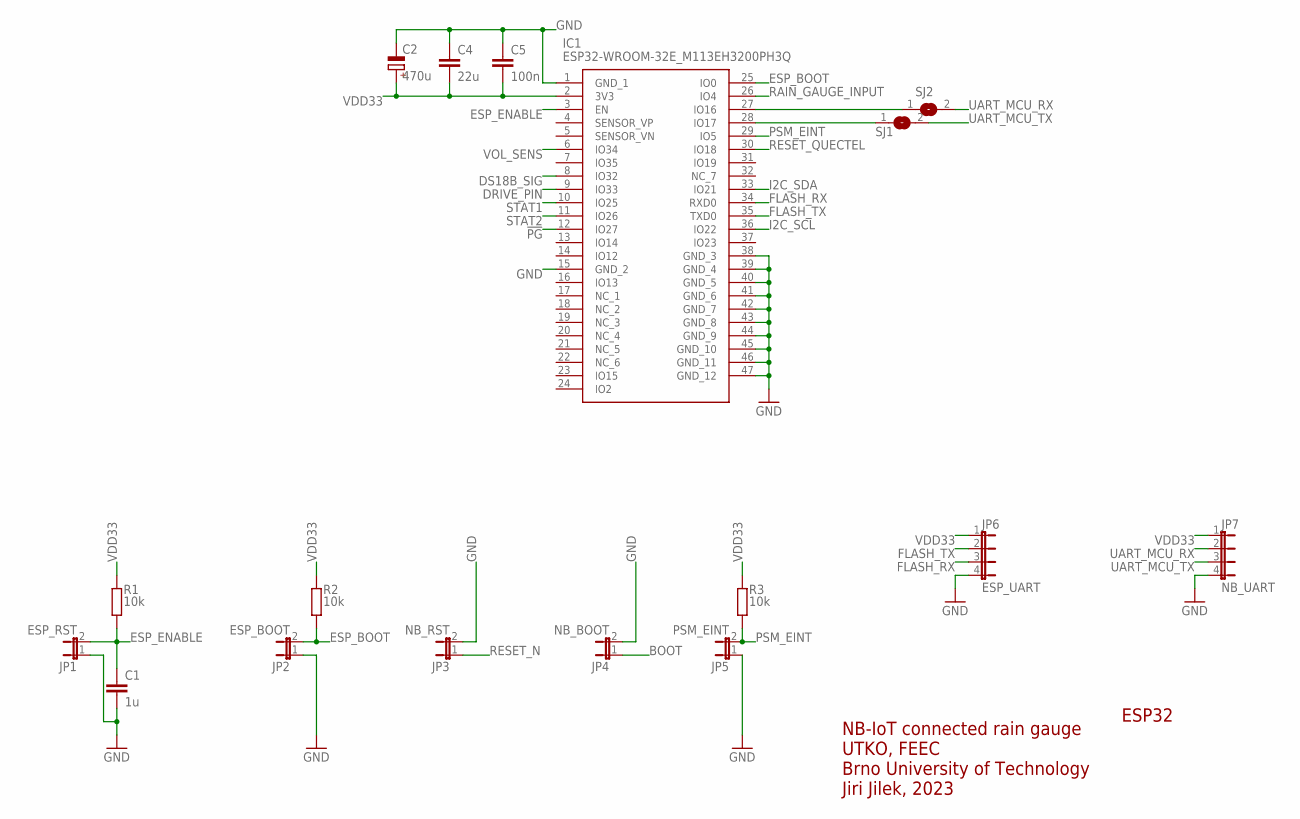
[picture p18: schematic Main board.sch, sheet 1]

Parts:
C1: 1u; C0603
C2: 470u; PANASONIC_D
C4: 22u; C0603
C5: 100n; C0603
IC1: ESP32-WROOM-32E_M113EH3200PH3Q; ESP32WROOM32EM113EH3200PH3Q0
JP1: ESP_RST; JP1
JP2: ESP_BOOT; JP1
JP3: NB_RST; JP1
JP4: NB_BOOT; JP1
JP5: PSM_EINT; JP1
JP6: ESP_UART; JP4
JP7: NB_UART; JP4
R1, R2, R3: 10k; R0603
SJ1, SJ2: SJ

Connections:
!PG: IC1.12 (IO27); also elsewhere on the board
BOOT: JP4.1; also elsewhere on the board
DRIVE_PIN: IC1.9 (IO33); also elsewhere on the board
DS18B_SIG: IC1.8 (IO32); also elsewhere on the board
ESP_BOOT: IC1.25 (IO0), JP2.2, R2.1
ESP_ENABLE: C1.1, IC1.3 (EN), JP1.2, R1.1
FLASH_RX: IC1.34 (RXD0), JP6.3
FLASH_TX: IC1.35 (TXD0), JP6.2
GND: C1.2, C2.-, C4.1, C5.1, IC1.1 (GND_1), IC1.15 (GND_2), IC1.38 (GND_3), IC1.39 (GND_4), IC1.40 (GND_5), IC1.41 (GND_6), IC1.42 (GND_7), IC1.43 (GND_8), IC1.44 (GND_9), IC1.45 (GND_10), IC1.46 (GND_11), IC1.47 (GND_12), JP1.1, JP2.1, JP3.2, JP4.2, JP5.1, JP6.4, JP7.4; also elsewhere on the board
I2C_SCL: IC1.36 (IO22); also elsewhere on the board
I2C_SDA: IC1.33 (IO21); also elsewhere on the board
unnamed: IC1.27 (IO16), SJ2.1
unnamed: IC1.28 (IO17), SJ1.1
PSM_EINT: IC1.29 (IO5), JP5.2, R3.1; also elsewhere on the board
RAIN_GAUGE_INPUT: IC1.26 (IO4); also elsewhere on the board
RESET_N: JP3.1; also elsewhere on the board
RESET_QUECTEL: IC1.30 (IO18); also elsewhere on the board
STAT1: IC1.10 (IO25); also elsewhere on the board
STAT2: IC1.11 (IO26); also elsewhere on the board
UART_MCU_RX: JP7.2, SJ2.2; also elsewhere on the board
UART_MCU_TX: JP7.3, SJ1.2; also elsewhere on the board
VDD33: C2.+, C4.2, C5.2, IC1.2 (3V3), JP6.1, JP7.1, R1.2, R2.2, R3.2; also elsewhere on the board
VOL_SENS: IC1.6 (IO34); also elsewhere on the board

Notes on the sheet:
ESP32
NB-IoT connected rain gauge UTKO, FEEC Brno University of Technology Jiri Jilek, 2023

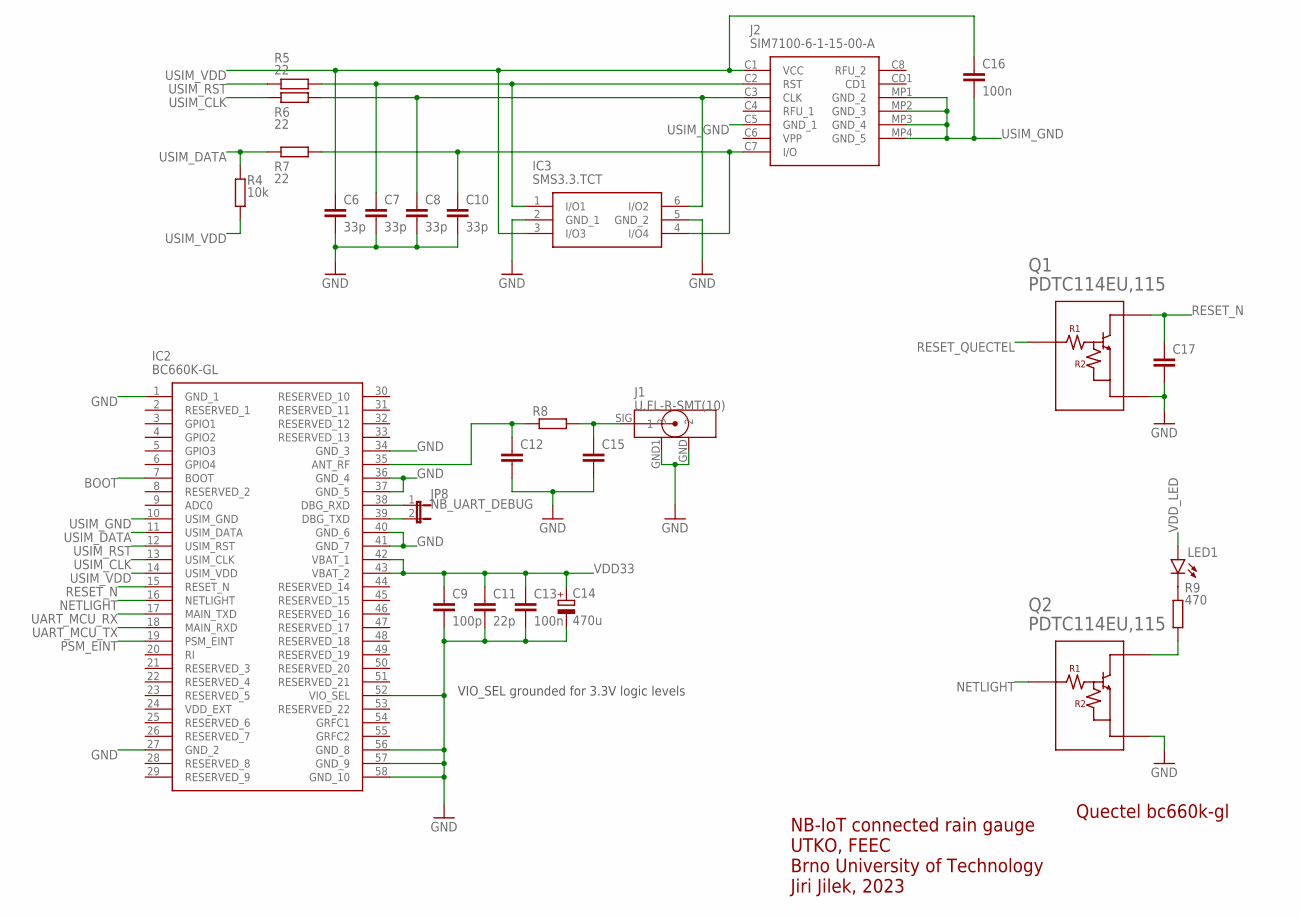
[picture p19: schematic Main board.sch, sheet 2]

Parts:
C6, C7, C8, C10: 33p; C0603
C9: 100p; C0603
C11: 22p; C0603
C12, C15, C17: C-EUC0603; C0603
C13, C16: 100n; C0603
C14: 470u; PANASONIC_D
IC2: BC660K-GL; BC660KGL
IC3: SMS3.3.TCT; SOT95P280X145-6N
J1: U.FL-R-SMT(10)
J2: SIM7100-6-1-15-00-A; SIM7100611500A
JP8: NB_UART_DEBUG; JP1
LED1: NETSTAT; CHIPLED_0805
Q1, Q2: PDTC114EU,115; SOT65P210X110-3N
R4: 10k; R0603
R5, R6, R7: 22; R0603
R8: R-EU_R0603; R0603
R9: 470; R0603

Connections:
BOOT: IC2.7 (BOOT); also elsewhere on the board
GND: C6.2, C7.2, C8.2, C9.2, C10.2, C11.2, C12.2, C13.2, C14.-, C15.2, C17.2, IC2.1 (GND_1), IC2.27 (GND_2), IC2.34 (GND_3), IC2.36 (GND_4), IC2.37 (GND_5), IC2.40 (GND_6), IC2.41 (GND_7), IC2.52 (VIO_SEL), IC2.56 (GND_8), IC2.57 (GND_9), IC2.58 (GND_10), IC3.2 (GND_1), IC3.5 (GND_2), J1.GND (2), J1.GND1 (3), Q1.2 (GND), Q2.2 (GND); also elsewhere on the board
unnamed: IC2.38 (DBG_RXD), JP8.1
unnamed: IC2.39 (DBG_TXD), JP8.2
unnamed: LED1.C, R9.2
unnamed: Q2.3 (OUTPUT), R9.1
unnamed: C12.1, IC2.35 (ANT_RF), R8.1
unnamed: C15.1, J1.SIG (1), R8.2
unnamed: C7.1, IC3.1 (I/O1), J2.C2 (RST), R5.2
unnamed: C8.1, IC3.6 (I/O2), J2.C3 (CLK), R6.2
unnamed: C10.1, IC3.4 (I/O4), J2.C7 (I/O), R7.2
NETLIGHT: IC2.16 (NETLIGHT), Q2.1 (INPUT)
PSM_EINT: IC2.19 (PSM_EINT); also elsewhere on the board
RESET_N: C17.1, IC2.15 (RESET_N), Q1.3 (OUTPUT); also elsewhere on the board
RESET_QUECTEL: Q1.1 (INPUT); also elsewhere on the board
UART_MCU_RX: IC2.17 (MAIN_TXD); also elsewhere on the board
UART_MCU_TX: IC2.18 (MAIN_RXD); also elsewhere on the board
USIM_CLK: IC2.13 (USIM_CLK), R6.1
USIM_DATA: IC2.11 (USIM_DATA), R4.2, R7.1
USIM_GND: C16.2, IC2.10 (USIM_GND), J2.C5 (GND_1), J2.MP1 (GND_2), J2.MP2 (GND_3), J2.MP3 (GND_4), J2.MP4 (GND_5)
USIM_RST: IC2.12 (USIM_RST), R5.1
USIM_VDD: C6.1, C16.1, IC2.14 (USIM_VDD), IC3.3 (I/O3), J2.C1 (VCC), R4.1
VDD33: C9.1, C11.1, C13.1, C14.+, IC2.42 (VBAT_1), IC2.43 (VBAT_2); also elsewhere on the board
VDD_LED: LED1.A; also elsewhere on the board

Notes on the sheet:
Quectel bc660k-gl
VIO_SEL grounded for 3.3V logic levels
NB-IoT connected rain gauge UTKO, FEEC Brno University of Technology Jiri Jilek, 2023

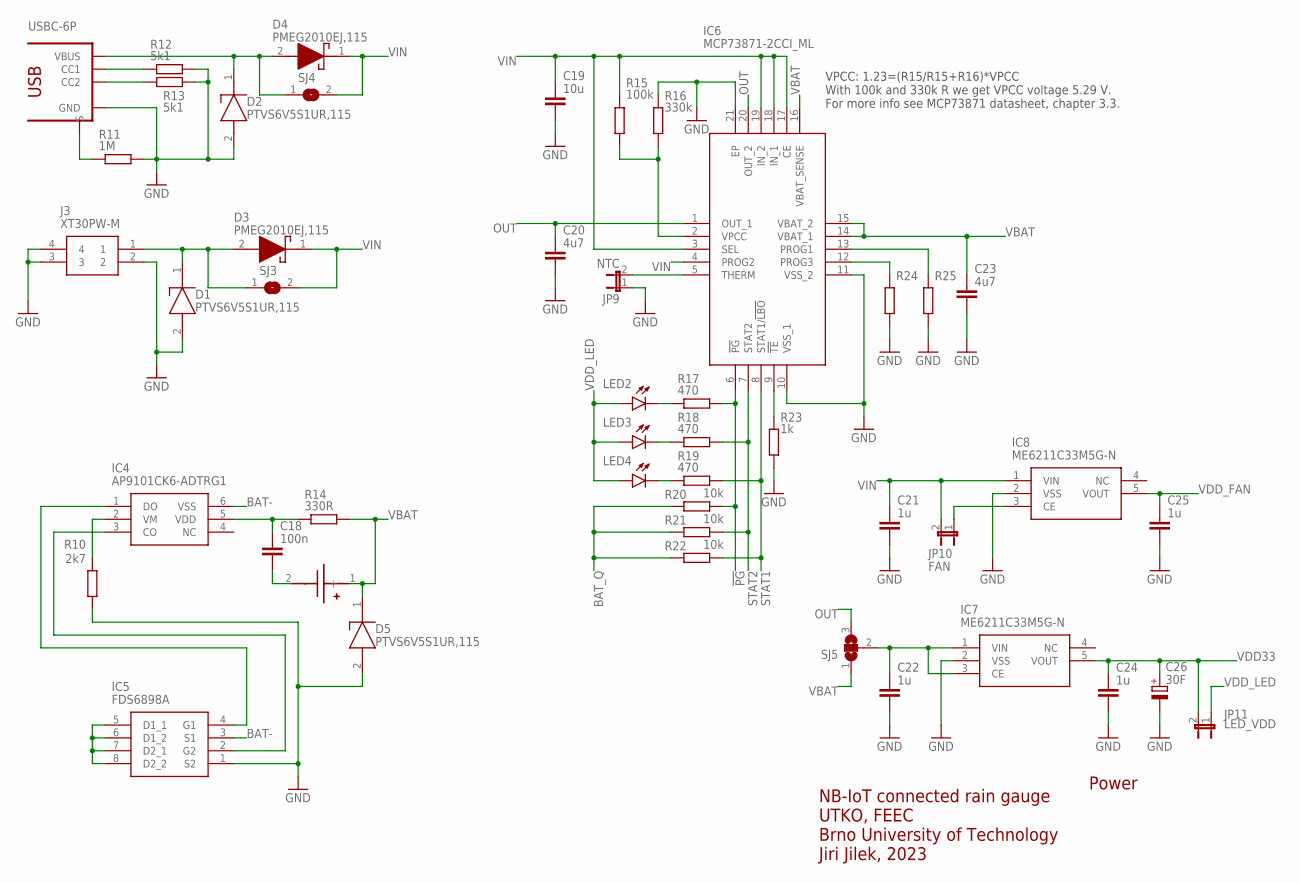
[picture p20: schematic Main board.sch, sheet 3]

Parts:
$3_29_$_2023-03-21_17-43-41: USBC-6P; USCX-06FX-XXMX-01
$3_30_$_2023-03-21_17-43-41: BLOSSOM-BLM-18650-1PCS
C18: 100n; C0603
C19: 10u; C0603
C20, C23: 4u7; C0603
C21, C22, C24, C25: 1u; C0603
C26: 30F; E5-10,5
D1, D2, D5: PTVS6V5S1UR,115; SOD123W
D3, D4: PMEG2010EJ,115; SODFL2512X80N
IC4: AP9101CK6-ADTRG1; SOT95P285X140-6N
IC5: FDS6898A; SOIC127P600X175-8N
IC6: MCP73871-2CCI_ML; QFN50P400X400X100-21N
IC7, IC8: ME6211C33M5G-N; SOT95P270X145-5N
J3: XT30PW-M; XT30PWM
JP9: NTC; JP1
JP10: FAN; JP1
JP11: LED_VDD; JP1
LED2: !PG; CHIPLED_0805
LED3: STAT2; CHIPLED_0805
LED4: STAT1; CHIPLED_0805
R10: 2k7; R0805
R11: 1M; R0603
R12, R13: 5k1; R0603
R14: 330R; R0603
R15: 100k; R0805
R16: 330k; R0805
R17, R18, R19: 470; R0603
R20, R21, R22: 10k; R0603
R23: 1k; R0603
R24, R25: R-EU_R0805; R0805
SJ3, SJ4: SJ
SJ5: SJ2W; SJ_2

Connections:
!PG: IC6.6 (!PG), R17.2, R20.2; also elsewhere on the board
!TE1: IC6.9 (!TE), R23.1
BAT-: $3_30_$_2023-03-21_17-43-41.2 (-), C18.2, IC4.6 (VSS), IC5.3 (S1)
BAT_Q: R20.1, R21.1, R22.1; also elsewhere on the board
CC3: $3_29_$_2023-03-21_17-43-41.CC2, R13.1
CC4: $3_29_$_2023-03-21_17-43-41.CC1, R12.1
DRAIN1: IC5.5 (D1_1), IC5.6 (D1_2), IC5.7 (D2_1), IC5.8 (D2_2)
G3: IC4.1 (DO), IC5.4 (G1)
G4: IC4.3 (CO), IC5.2 (G2)
GND: $3_29_$_2023-03-21_17-43-41.GND1 (GND), $3_29_$_2023-03-21_17-43-41.GND2 (GND), C19.2, C20.2, C21.2, C22.2, C23.2, C24.2, C25.2, C26.-, D1.2 (A), D2.2 (A), D5.2 (A), IC5.1 (S2), IC6.10 (VSS_1), IC6.11 (VSS_2), IC6.21 (EP), IC7.2 (VSS), IC8.2 (VSS), J3.2, J3.3, J3.4, JP9.1, R10.1, R11.2, R12.2, R13.2, R16.2, R23.2, R24.2, R25.2; also elsewhere on the board
unnamed: C18.1, IC4.5 (VDD), R14.1
unnamed: IC8.3 (CE), JP10.1
unnamed: LED2.C, R17.1
unnamed: LED3.C, R18.1
unnamed: LED4.C, R19.1
OUT: C20.1, IC6.1 (OUT_1), IC6.20 (OUT_2), SJ5.3
PROG1: IC6.13 (PROG1), R25.1
PROG3: IC6.12 (PROG3), R24.1
PV_IN1: D1.1 (K), D3.2 (A), J3.1, SJ3.1
S1: $3_29_$_2023-03-21_17-43-41.SHIELD1 (S), $3_29_$_2023-03-21_17-43-41.SHIELD2 (S), $3_29_$_2023-03-21_17-43-41.SHIELD3 (S), $3_29_$_2023-03-21_17-43-41.SHIELD4 (S), R11.1
STAT1: IC6.8 (STAT1/!LBO), R19.2, R22.2; also elsewhere on the board
STAT2: IC6.7 (STAT2), R18.2, R21.2; also elsewhere on the board
THERM1: IC6.5 (THERM), JP9.2
VBAT: $3_30_$_2023-03-21_17-43-41.1 (+), C23.1, D5.1 (K), IC6.14 (VBAT_1), IC6.15 (VBAT_2), IC6.16 (VBAT_SENSE), R14.2, SJ5.1; also elsewhere on the board
VBUS1: $3_29_$_2023-03-21_17-43-41.VBUS1 (VBUS), $3_29_$_2023-03-21_17-43-41.VBUS2 (VBUS), D2.1 (K), D4.2 (A), SJ4.1
VDD33: C24.1, C26.+, IC7.5 (VOUT), JP11.2; also elsewhere on the board
VDD_FAN: C25.1, IC8.5 (VOUT); also elsewhere on the board
VDD_LED: JP11.1, LED2.A, LED3.A, LED4.A; also elsewhere on the board
VIN: C19.1, C21.1, D3.1 (K), D4.1 (K), IC6.3 (SEL), IC6.4 (PROG2), IC6.17 (CE), IC6.18 (IN_1), IC6.19 (IN_2), IC8.1 (VIN), JP10.2, R15.2, SJ3.2, SJ4.2
VIN_LDO: C22.1, IC7.1 (VIN), IC7.3 (CE), SJ5.2
VM1: IC4.2 (VM), R10.2
VPCC1: IC6.2 (VPCC), R15.1, R16.1

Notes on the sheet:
Power
VPCC: 1.23=(R15/R15+R16)*VPCC With 100k and 330k R we get VPCC voltage 5.29 V. For more info see MCP73871 datasheet, chapter 3.3.
NB-IoT connected rain gauge UTKO, FEEC Brno University of Technology Jiri Jilek, 2023

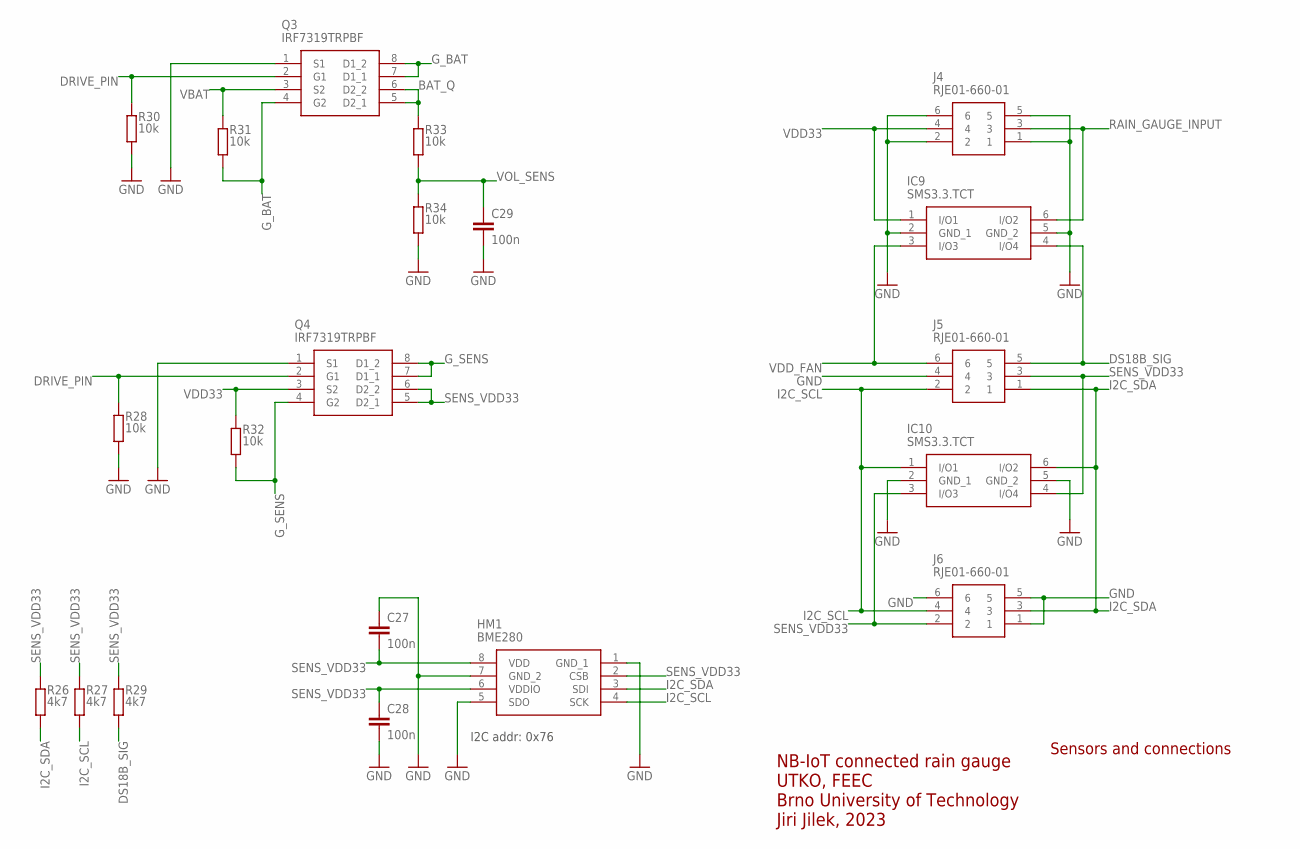
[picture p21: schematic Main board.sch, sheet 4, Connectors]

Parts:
C27, C28, C29: 100n; C0805
HM1: BME280
IC9, IC10: SMS3.3.TCT; SOT95P280X145-6N
J4, J5, J6: RJE01-660-01; RJE0166001
Q3, Q4: IRF7319TRPBF; SOIC127P600X175-8N
R26, R27, R29: 4k7; R0805
R28, R30, R31, R32, R33, R34: 10k; R0805

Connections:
BAT_Q: Q3.5 (D2_1), Q3.6 (D2_2), R33.2; also elsewhere on the board
DRIVE_PIN: Q3.2 (G1), Q4.2 (G1), R28.2, R30.2; also elsewhere on the board
DS18B_SIG: IC9.4 (I/O4), J5.5, R29.1; also elsewhere on the board
GND: C27.1, C28.2, C29.2, HM1.1 (GND_1), HM1.5 (SDO), HM1.7 (GND_2), IC9.2 (GND_1), IC9.5 (GND_2), IC10.2 (GND_1), IC10.5 (GND_2), J4.1, J4.2, J4.5, J4.6, J5.4, J6.1, J6.5, J6.6, Q3.1 (S1), Q4.1 (S1), R28.1, R30.1, R34.1; also elsewhere on the board
G_BAT: Q3.4 (G2), Q3.7 (D1_1), Q3.8 (D1_2), R31.2
G_SENS: Q4.4 (G2), Q4.7 (D1_1), Q4.8 (D1_2), R32.2
I2C_SCL: HM1.4 (SCK), IC10.1 (I/O1), J5.2, J6.4, R27.1; also elsewhere on the board
I2C_SDA: HM1.3 (SDI), IC10.6 (I/O2), J5.1, J6.3, R26.1; also elsewhere on the board
RAIN_GAUGE_INPUT: IC9.6 (I/O2), J4.3; also elsewhere on the board
SENS_VDD33: C27.2, C28.1, HM1.2 (CSB), HM1.6 (VDDIO), HM1.8 (VDD), IC10.3 (I/O3), IC10.4 (I/O4), J5.3, J6.2, Q4.5 (D2_1), Q4.6 (D2_2), R26.2, R27.2, R29.2
VBAT: Q3.3 (S2), R31.1; also elsewhere on the board
VDD33: IC9.1 (I/O1), J4.4, Q4.3 (S2), R32.1; also elsewhere on the board
VDD_FAN: IC9.3 (I/O3), J5.6; also elsewhere on the board
VOL_SENS: C29.1, R33.1, R34.2; also elsewhere on the board

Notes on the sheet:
Sensors and connections
I2C addr: 0x76
NB-IoT connected rain gauge UTKO, FEEC Brno University of Technology Jiri Jilek, 2023

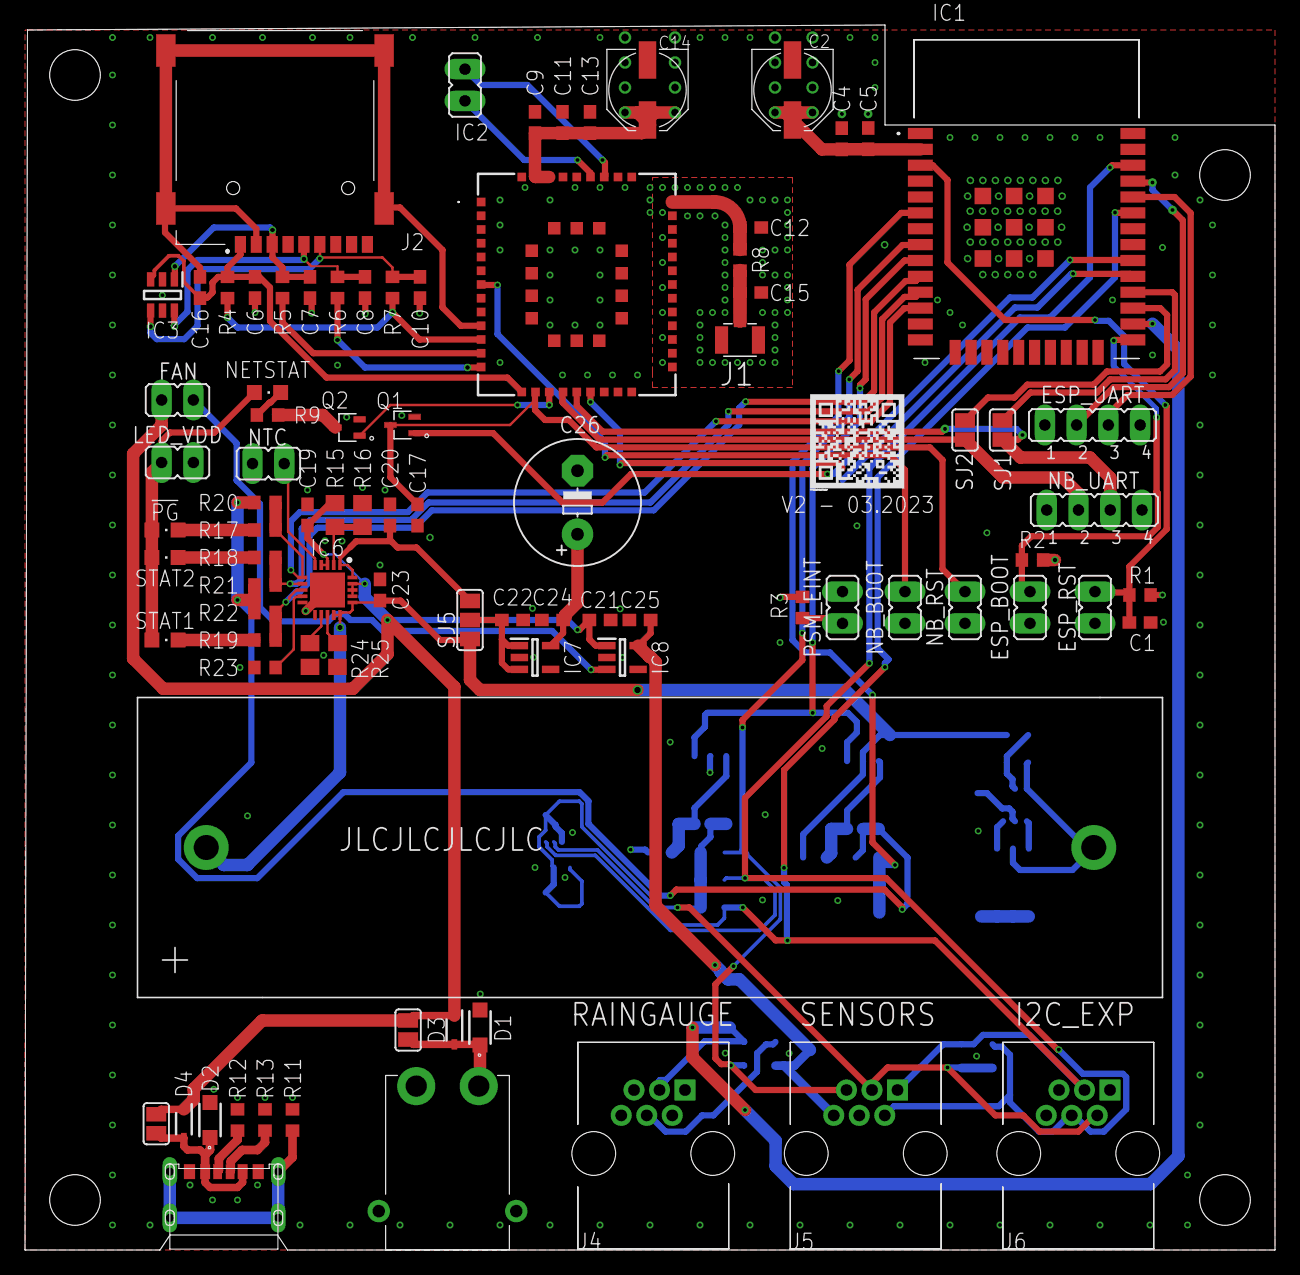
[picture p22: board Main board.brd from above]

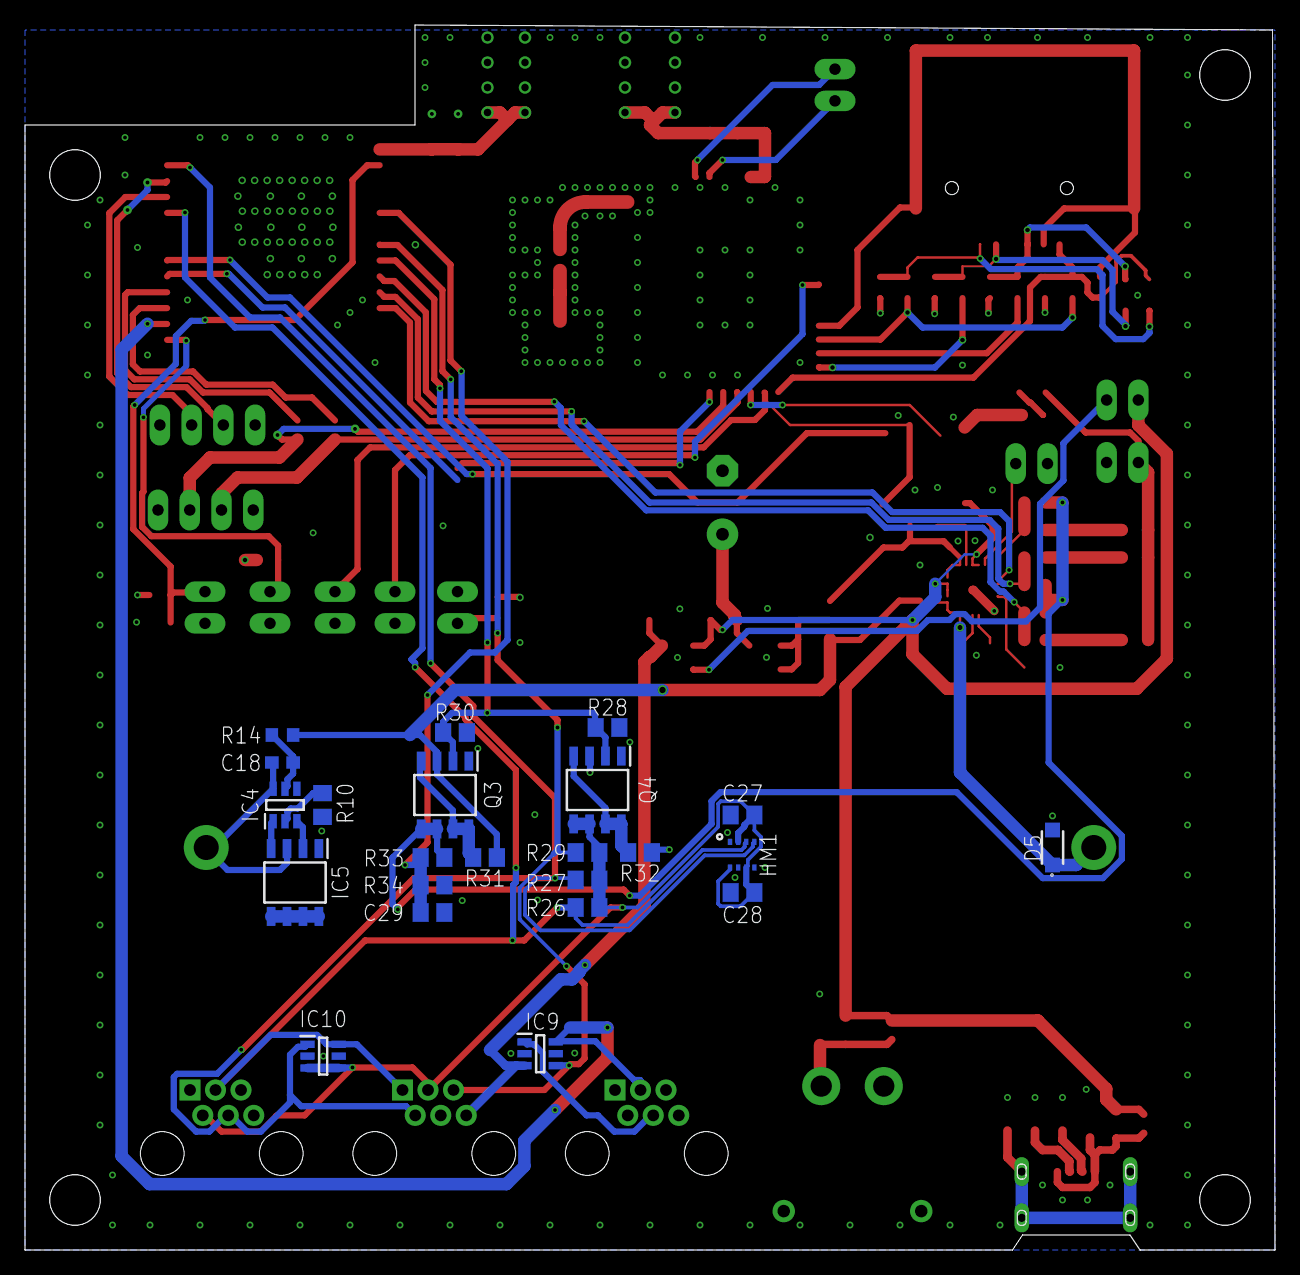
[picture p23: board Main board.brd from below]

Board: 4 copper layers, 100.0 x 98.0 mm, 110 parts (23 on the bottom side), 68 nets.

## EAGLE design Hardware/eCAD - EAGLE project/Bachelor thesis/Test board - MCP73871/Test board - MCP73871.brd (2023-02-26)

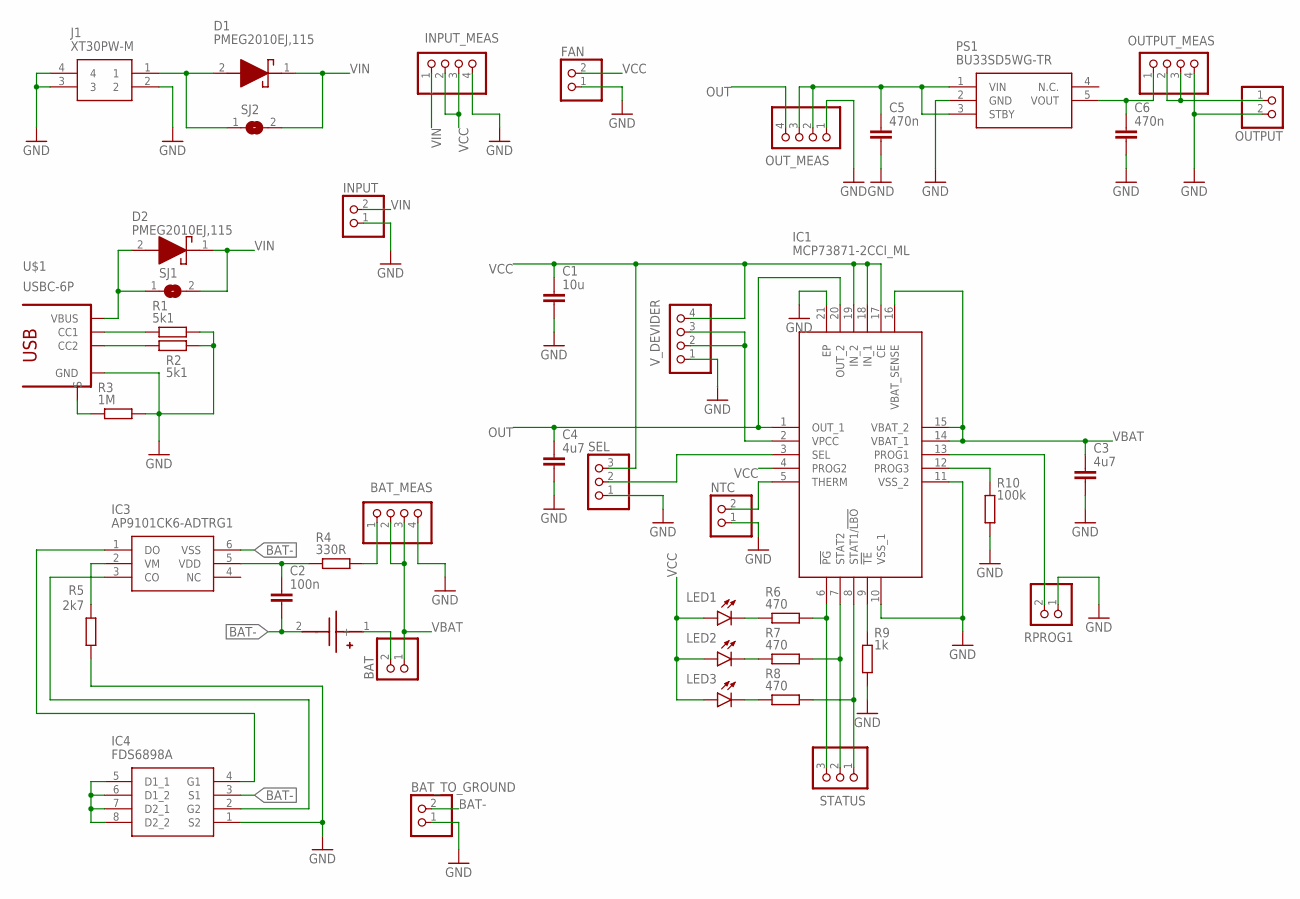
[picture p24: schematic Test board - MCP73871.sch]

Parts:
BAT: PINHD-1X2; 1X02
BAT_MEAS: PINHD-1X4; 1X04
BAT_TO_GROUND: PINHD-1X2; 1X02
C1: 10u; C0805
C2: 100n; C0805
C3, C4: 4u7; C0805
C5, C6: 470n; C0805
D1, D2: PMEG2010EJ,115; SODFL2512X80N
FAN: PINHD-1X2; 1X02
IC1: MCP73871-2CCI_ML; QFN50P400X400X100-21N
IC3: AP9101CK6-ADTRG1; SOT95P285X140-6N
IC4: FDS6898A; SOIC127P600X175-8N
INPUT: PINHD-1X2; 1X02
INPUT_MEAS: PINHD-1X4; 1X04
J1: XT30PW-M; XT30PWM
LED1: !PG; CHIPLED_0805
LED2: STAT2; CHIPLED_0805
LED3: STAT1; CHIPLED_0805
NTC: PINHD-1X2; 1X02
OUTPUT: PINHD-1X2; 1X02
OUTPUT_MEAS: PINHD-1X4; 1X04
OUT_MEAS: PINHD-1X4; 1X04
PS1: BU33SD5WG-TR; SOT95P280X125-5N
R1, R2: 5k1; R0805
R3: 1M; R0805
R4: 330R; R0805
R5: 2k7; R0805
R6, R7, R8: 470; R0805
R9: 1k; R0805
R10: 100k; R0805
RPROG1: PINHD-1X2; 1X02
SEL: PINHD-1X3; 1X03
SJ1, SJ2: SJ
STATUS: PINHD-1X3; 1X03
U$1: USBC-6P; USCX-06FX-XXMX-01
U$2: BLOSSOM-BLM-18650-1PCS
V_DEVIDER: PINHD-1X4; 1X04

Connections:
!PG: IC1.6 (!PG), R6.2, STATUS.3
!TE: IC1.9 (!TE), R9.1
BAT+: BAT.2, U$2.1 (+)
BAT-: BAT_TO_GROUND.2, C2.2, IC3.6 (VSS), IC4.3 (S1), U$2.2 (-)
CC1: R1.1, U$1.CC1
CC2: R2.1, U$1.CC2
DRAIN: IC4.5 (D1_1), IC4.6 (D1_2), IC4.7 (D2_1), IC4.8 (D2_2)
G1: IC3.1 (DO), IC4.4 (G1)
G2: IC3.3 (CO), IC4.2 (G2)
GND: BAT_MEAS.4, BAT_TO_GROUND.1, C1.2, C3.2, C4.2, C5.2, C6.2, FAN.1, IC1.10 (VSS_1), IC1.11 (VSS_2), IC1.21 (EP), IC4.1 (S2), INPUT.1, INPUT_MEAS.4, J1.2, J1.3, J1.4, NTC.1, OUTPUT.2, OUTPUT_MEAS.4, OUT_MEAS.1, PS1.2 (GND), R1.2, R2.2, R3.2, R5.1, R9.2, R10.2, RPROG1.1, SEL.1, U$1.GND1 (GND), U$1.GND2 (GND), V_DEVIDER.1
LDO_VIN: C5.1, OUT_MEAS.2, OUT_MEAS.3, PS1.1 (VIN), PS1.3 (STBY)
unnamed: C2.1, IC3.5 (VDD), R4.1
unnamed: LED1.C, R6.1
unnamed: LED2.C, R7.1
unnamed: LED3.C, R8.1
unnamed: BAT_MEAS.1, R4.2
OUT: C4.1, IC1.1 (OUT_1), IC1.20 (OUT_2), OUT_MEAS.4
OUTPUT: OUTPUT.1, OUTPUT_MEAS.2, OUTPUT_MEAS.3
PROG1: IC1.13 (PROG1), RPROG1.2
PROG3: IC1.12 (PROG3), R10.1
PV_IN: D1.2 (A), J1.1, SJ2.1
S: R3.1, U$1.SHIELD1 (S), U$1.SHIELD2 (S), U$1.SHIELD3 (S), U$1.SHIELD4 (S)
SEL: IC1.3 (SEL), SEL.2
STAT1: IC1.8 (STAT1/!LBO), R8.2, STATUS.1
STAT2: IC1.7 (STAT2), R7.2, STATUS.2
THERM: IC1.5 (THERM), NTC.2
VBAT: BAT.1, BAT_MEAS.2, BAT_MEAS.3, C3.1, IC1.14 (VBAT_1), IC1.15 (VBAT_2), IC1.16 (VBAT_SENSE)
VBUS: D2.2 (A), SJ1.1, U$1.VBUS1 (VBUS), U$1.VBUS2 (VBUS)
VCC: C1.1, FAN.2, IC1.4 (PROG2), IC1.17 (CE), IC1.18 (IN_1), IC1.19 (IN_2), INPUT_MEAS.2, INPUT_MEAS.3, LED1.A, LED2.A, LED3.A, SEL.3, V_DEVIDER.4
VIN: D1.1 (K), D2.1 (K), INPUT.2, INPUT_MEAS.1, SJ1.2, SJ2.2
VM: IC3.2 (VM), R5.2
VOUT: C6.1, OUTPUT_MEAS.1, PS1.5 (VOUT)
VPCC: IC1.2 (VPCC), V_DEVIDER.2, V_DEVIDER.3

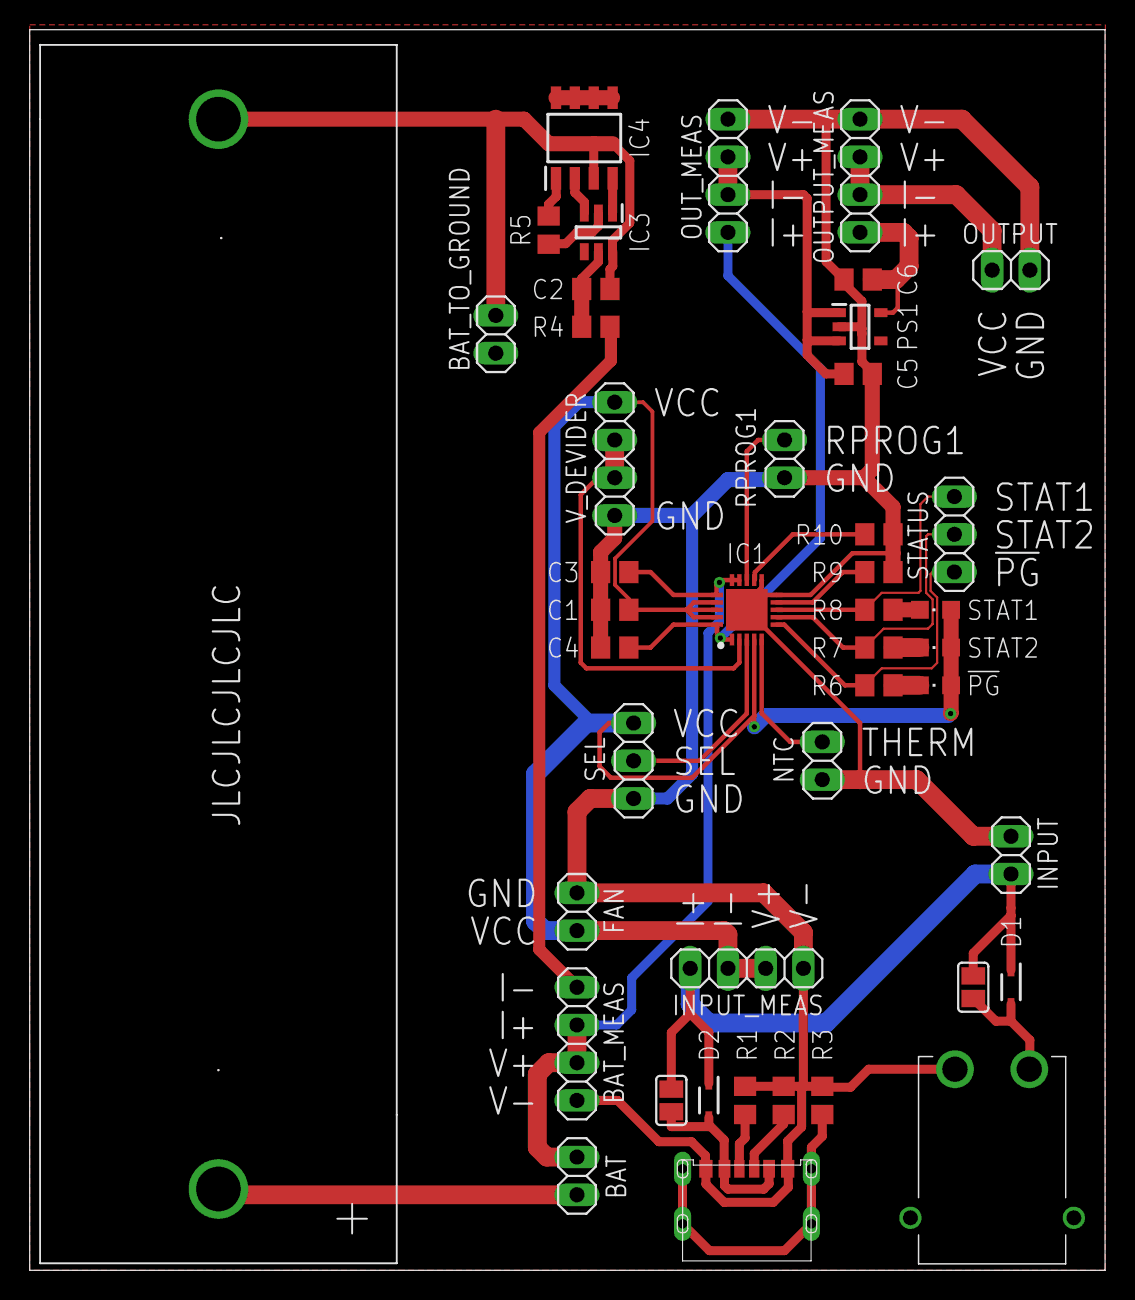
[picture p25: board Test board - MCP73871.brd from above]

Board: 2 copper layers, 72.4 x 83.5 mm, 44 parts (0 on the bottom side), 33 nets.

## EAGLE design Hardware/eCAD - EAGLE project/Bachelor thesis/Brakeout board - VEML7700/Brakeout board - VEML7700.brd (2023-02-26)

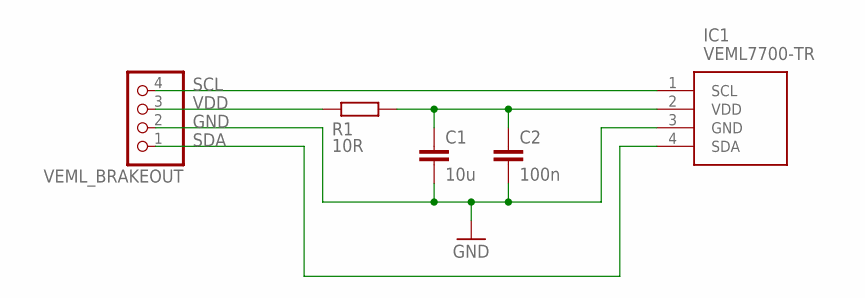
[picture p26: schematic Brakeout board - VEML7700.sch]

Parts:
C1: 10u; C0805
C2: 100n; C0805
IC1: VEML7700-TR; VEML7700
R1: 10R; R0805
VEML_BRAKEOUT: PINHD-1X4; 1X04

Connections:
GND: C1.2, C2.2, IC1.3 (GND), VEML_BRAKEOUT.2
unnamed: C1.1, C2.1, IC1.2 (VDD), R1.2
SCL: IC1.1 (SCL), VEML_BRAKEOUT.4
SDA: IC1.4 (SDA), VEML_BRAKEOUT.1
VDD: R1.1, VEML_BRAKEOUT.3

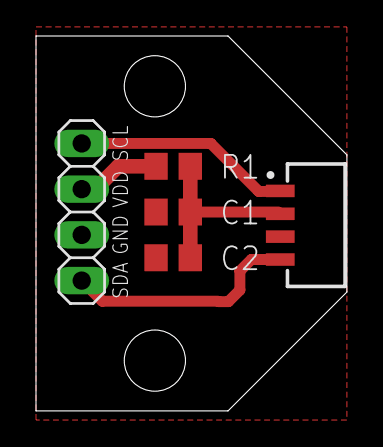
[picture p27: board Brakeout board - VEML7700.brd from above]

Board: 2 copper layers, 17.3 x 20.8 mm, 5 parts (0 on the bottom side), 5 nets.

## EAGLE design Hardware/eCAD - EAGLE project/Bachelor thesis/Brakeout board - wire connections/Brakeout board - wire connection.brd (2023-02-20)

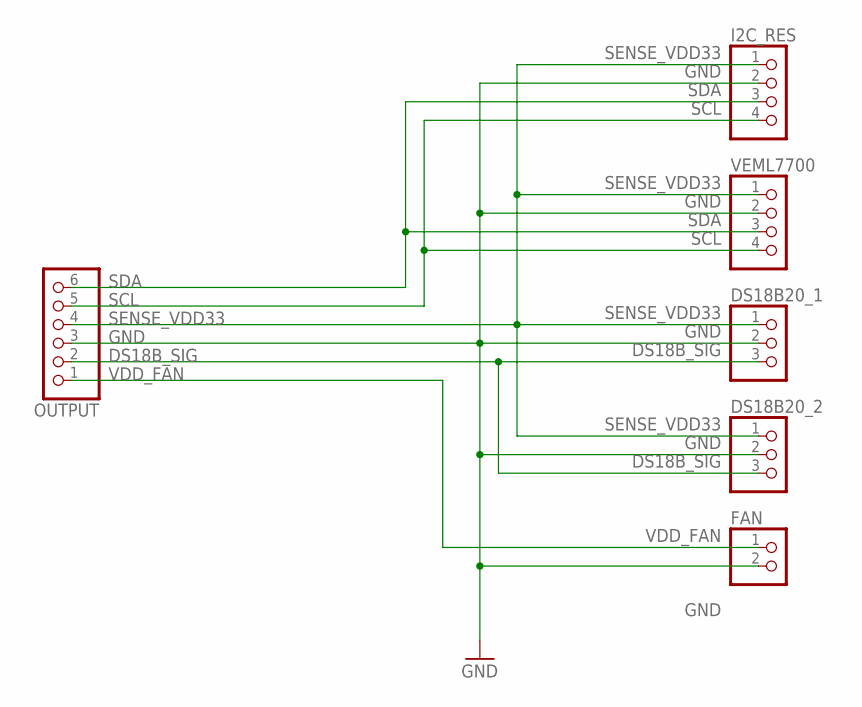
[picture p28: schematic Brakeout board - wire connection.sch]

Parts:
DS18B20_1, DS18B20_2: PINHD-1X3; 1X03
FAN: PINHD-1X2; 1X02
I2C_RES: PINHD-1X4; 1X04
OUTPUT: PINHD-1X6; 1X06
VEML7700: PINHD-1X4; 1X04

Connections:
DS18B_SIG: DS18B20_1.3, DS18B20_2.3, OUTPUT.2
GND: DS18B20_1.2, DS18B20_2.2, FAN.2, I2C_RES.2, OUTPUT.3, VEML7700.2
SCL: I2C_RES.4, OUTPUT.5, VEML7700.4
SDA: I2C_RES.3, OUTPUT.6, VEML7700.3
SENSE_VDD33: DS18B20_1.1, DS18B20_2.1, I2C_RES.1, OUTPUT.4, VEML7700.1
VDD_FAN: FAN.1, OUTPUT.1

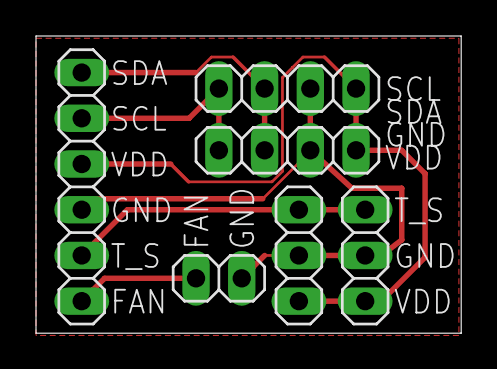
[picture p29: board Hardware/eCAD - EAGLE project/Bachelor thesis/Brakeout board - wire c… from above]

Board: 2 copper layers, 23.6 x 16.5 mm, 6 parts (0 on the bottom side), 6 nets.

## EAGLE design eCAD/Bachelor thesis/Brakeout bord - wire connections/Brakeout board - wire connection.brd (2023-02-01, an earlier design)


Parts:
DS18B20: PINHD-1X3; 1X03
FAN: PINHD-1X2; 1X02
IC1: VEML7700-TR; VEML7700
OUTPUT: PINHD-1X6; 1X06
VEML7700: PINHD-1X4; 1X04
VEML_BRAKEOUT: PINHD-1X4; 1X04

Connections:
DS18B_SIG: DS18B20.3, OUTPUT.2
GND: DS18B20.2, FAN.2, IC1.3 (GND), OUTPUT.3, VEML7700.2, VEML_BRAKEOUT.2
SCL: OUTPUT.5, VEML7700.4
SDA: OUTPUT.6, VEML7700.3
SENSE_VDD33: DS18B20.1, OUTPUT.4, VEML7700.1
VDD: IC1.2 (VDD), VEML_BRAKEOUT.3
VDD_FAN: FAN.1, OUTPUT.1
VEML_SCL: IC1.1 (SCL), IC1.4 (SDA), VEML_BRAKEOUT.1, VEML_BRAKEOUT.4


Board: 2 copper layers, 50.0 x 20.0 mm, 6 parts (0 on the bottom side), 8 nets.

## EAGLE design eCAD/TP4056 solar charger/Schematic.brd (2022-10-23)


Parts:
C1, C5: 10u; C0805
C2: 100n; C0805
C3, C4: 470n; C0805
D1: STPS2L30A; DIOM5126X265N
IC1: TP4056X; SOIC127P600X175-9N
IC2: AP9101CK6-ADTRG1; SOT95P285X140-6N
IC3: FDS6898A; SOIC127P600X175-8N
JP1: !CHRG; 1X01
JP2: !STDBY; 1X01
JP3: VIN; 1X01
JP4: OUT+; 1X01
JP5: BAT_V; 1X01
LED1: GREEN; CHIPLED_0805
LED2: RED; CHIPLED_0805
PS1: BU33SD5WG-TR; SOT95P280X125-5N
Q1: SI2347DS-T1-GE3; SOT95P237X112-3N
R1, R2: 1k; R0805
R3: Rprog; R0805
R4: 330R; R0805
R5: 2k7; R0805
R6: 10k; R0805
R7, R8: 5k1; R0805
R9: 1M; R0805
R10: 27K; R0805
R11: 100k; R0805
U$1: USBC-6P; USCX-06FX-XXMX-01
X1: PV_PANEL; AK300/2
X2: BATTERY; AK300/2
X3: OUTPUT; AK300/2

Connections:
BAT-: C2.2, IC2.6 (VSS), IC3.3 (S1), X2.2
GND: C1.2, C3.2, C4.2, C5.2, IC1.1 (TEMP), IC1.3 (GND), IC1.9 (EAD), IC3.1 (S2), PS1.2 (GND), R3.2, R5.1, R6.1, R7.1, R8.1, R9.2, R11.1, U$1.GND1 (GND), U$1.GND2 (GND), X1.2, X3.2
unnamed: LED1.C, R1.2
unnamed: LED2.C, R2.2
unnamed: IC1.6 (!STDBY), JP2.1, R1.1
unnamed: IC1.2 (PROG), R3.1
unnamed: C2.1, IC2.5 (VDD), R4.1
unnamed: IC1.7 (!CHRG), JP1.1, R2.1
unnamed: R9.1, U$1.SHIELD1 (S), U$1.SHIELD2 (S), U$1.SHIELD3 (S), U$1.SHIELD4 (S)
unnamed: R8.2, U$1.CC2
unnamed: IC2.2 (VM), R5.2
unnamed: IC2.1 (DO), IC3.4 (G1)
unnamed: R7.2, U$1.CC1
unnamed: IC2.3 (CO), IC3.2 (G2)
unnamed: IC3.5 (D1_1), IC3.6 (D1_2), IC3.7 (D2_1), IC3.8 (D2_2)
unnamed: C4.1, PS1.5 (VOUT), X3.1
unnamed: JP5.1, R10.1, R11.2
OUPUT: IC1.5 (BAT)
OUT+: C3.1, D1.1 (K), JP4.1, PS1.1 (VIN), PS1.3 (STBY), Q1.2 (S)
OUTPUT: C5.1, Q1.3 (D), R4.2, R10.2, X2.1
VIN: C1.1, D1.2 (A), IC1.4 (VCC), IC1.8 (CE), JP3.1, LED1.A, LED2.A, Q1.1 (G), R6.2, U$1.VBUS1 (VBUS), U$1.VBUS2 (VBUS), X1.1

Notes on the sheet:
TEMP is grounded to disable temperature riden stop charge

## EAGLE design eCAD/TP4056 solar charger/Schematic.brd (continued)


Board: 2 copper layers, 71.1 x 28.9 mm, 33 parts (0 on the bottom side), 20 nets.

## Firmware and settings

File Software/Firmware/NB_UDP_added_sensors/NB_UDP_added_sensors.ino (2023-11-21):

#include <credentials.h>       // Credentials for NB module and server - contains IP address of NB-IoT server in char nbSERVER[]
#include <ESP32Time.h>         // https://github.com/fbiego/ESP32Time
#include <OneWire.h>           // https://www.arduino.cc/reference/en/libraries/onewire/
#include <DallasTemperature.h> // https://github.com/milesburton/Arduino-Temperature-Control-Library
#include <Quectel_BC660.h>     // https://github.com/R4sp1/Quectel-BC660/tree/dev
#include "Adafruit_VEML7700.h" // https://github.com/adafruit/Adafruit_VEML7700
#include "Adafruit_SHT4x.h"    // https://github.com/adafruit/Adafruit_SHT4X
#include <Adafruit_BME280.h>   // https://github.com/adafruit/Adafruit_BME280_Library

#define DEBUG         // Uncomment this line if you want to print out to serial "debug" messages
#define DEVICE_ADDRESS 1 // Device address (1-255) used to identify device on server

// Deep sleep related definitions
#define uS_TO_S_FACTOR 1000000 // Conversion factor for micro seconds to seconds
#define TIME_TO_SLEEP 300      // ESP32 will go to sleep for 5 minutes (in seconds)

// NB related definitions
#define SERIAL_PORT Serial2
#define RST 18       // MCU pin to control module reset
#define PSM 5        // MCU pin to control module wake up pin (PSM-EINT_N)
#define NBdelay 1000 // Delay between two AT commands
#define DEB false    // True or False debug option
const char *nbServer = nbSERVER;
int nbPort = 1883;
QuectelBC660 quectel = QuectelBC660(PSM, DEB);

// Sensors related definitions
#define TPIN 32     // DS18B20 pin
#define VOL_SENS 34 // Pin to measure voltage of battery
#define CAL 2       // Voltage devider ratio
#define EN 33       // Pin to power on sensors

// Data stored in RTC memory
RTC_DATA_ATTR ulong wakeUpEpoch = 0;
RTC_DATA_ATTR int rainCount = 0;
RTC_DATA_ATTR int connectionTries = 0;

// Variables for sensors
float temp1 = -127;
float temp2 = -127;
float tempSHT45 = -127;
float humSHT45 = -127;
float tempBME280 = -127;
float humBME280 = -127;
float presBME280 = -127;
float light = -127;
float Voltage = 0;      // Voltage in mV
int volSens_Result = 0; // Raw value from ADC

// Sensors definitions
OneWire oneWire(TPIN); // OneWire
DallasTemperature oneWireTemp(&oneWire);
ESP32Time rtc;
Adafruit_VEML7700 veml = Adafruit_VEML7700();
Adafruit_SHT4x sht45 = Adafruit_SHT4x();
Adafruit_BME280 bme;
int vemlFix = 0;

int timeToSleep = 0;
ulong currentEpoch = 0;

unsigned long lastDebounceTime = 0; // the last time the raingauge was overturned
unsigned long debounceDelay = 200;  // the debounce time

// Function to round float to two decimal places
float round2(float val)
{
  if (val < 0) // Check if we are rounding negative number
  {
    return (int)(val * 100 - 0.5) / 100.0;
  }
  return (int)(val * 100 + 0.5) / 100.0;
}

// Function to print out wakeup reason
void print_wakeup_reason()
{
  esp_sleep_wakeup_cause_t wakeup_reason;
  wakeup_reason = esp_sleep_get_wakeup_cause();
  switch (wakeup_reason)
  {
  case ESP_SLEEP_WAKEUP_EXT0:
    Serial.println("Wakeup caused by external signal using RTC_IO");
    break;
  case ESP_SLEEP_WAKEUP_EXT1:
    Serial.println("Wakeup caused by external signal using RTC_CNTL");
    break;
  case ESP_SLEEP_WAKEUP_TIMER:
    Serial.println("Wakeup caused by timer");
    break;
  case ESP_SLEEP_WAKEUP_TOUCHPAD:
    Serial.println("Wakeup caused by touchpad");
    break;
  case ESP_SLEEP_WAKEUP_ULP:
    Serial.println("Wakeup caused by ULP program");
    break;
  default:
    Serial.printf("Wakeup was not caused by deep sleep: %d\n", wakeup_reason);
    break;
  }
}

// Function to setup sensors
void setupSensors()
{
  pinMode(EN, OUTPUT);    // Set pin to power on sensors as output
  digitalWrite(EN, HIGH); // Turn on sensors
  delay(100);             // Delay to let sensors "boot"
  oneWireTemp.begin();    // begin temp sensors on oneWire bus
  if (!veml.begin())      // begin light sensor
  {
    vemlFix = 1;
#ifdef DEBUG
    Serial.println("Sensor VEML7700 not found");
#endif
  }
  if (!sht45.begin())      // begin SHT45 temp and humidity sensor
  {
  #ifdef DEBUG
    Serial.println("SHT45 not found");
  #endif
  }
  if (!bme.begin(0x76)) // begin BME280 temp, humidity and pressure sensor
  {
  #ifdef DEBUG
    Serial.println("BME280 not found");
  #endif
  }
}

// Function to read data from sensors
void readSensors()
{
  // First Temp sensor
  oneWireTemp.requestTemperatures();      // Send command to measure temperatures on each sensor on the bus
  temp1 = oneWireTemp.getTempCByIndex(0); // Index 0 => first sensor on wire
#ifdef DEBUG
  Serial.print("First DS18B temp: ");
  Serial.print(temp1);
  Serial.println(" °C");
  Serial.println();
#endif

  // Second Temp sensor
  // oneWireTemp.requestTemperatures();   // Temp requested before first sensor read
  temp2 = oneWireTemp.getTempCByIndex(1); // Index 1 => second sensor on wire
#ifdef DEBUG
  Serial.print("Second DS18B temp: ");
  Serial.print(temp2);
  Serial.println(" °C");
  Serial.println();
#endif

  // Voltage of battery
  volSens_Result = 0;
  for (int i = 0; i < 16; i++) // Read 16 times and average
  {
    volSens_Result += analogReadMilliVolts(VOL_SENS);
    delay(5);
  }
  Voltage = (volSens_Result / 16.0); // Calculate voltage by deviding by 16 (16 reads) and multiplying by 2 (voltage devider) - voltage is in mV
#ifdef DEBUG
  Serial.print(Voltage / 1000.0); // Print Voltage (in V)
  Serial.println(" V");
  Serial.println(Voltage); // Print Voltage (in mV)
  Serial.println(" mV");
#endif

  // Light sensor
  if (vemlFix == 0)
  {
    light = veml.readLux(VEML_LUX_AUTO);
  }
#ifdef DEBUG
  Serial.print("Light: ");
  Serial.print(light);
  Serial.println(" lx");
#endif

  // SHT45 sensor
  sht45.setPrecision(SHT4X_HIGH_PRECISION); // highest resolution
  sht45.setHeater(SHT4X_NO_HEATER); // no heater
  sensors_event_t h, t;
  sht45.getEvent(&h, &t);
  tempSHT45 = t.temperature;
  humSHT45 = h.relative_humidity;
  #ifdef DEBUG
  Serial.print("SHT45 temperature: ");
  Serial.print(tempSHT45);
  Serial.println(" °C");
  Serial.print("SHT45 humidity: ");
  Serial.print(humSHT45);
  Serial.println("% rH");	
#endif
  
  // BME280 sensor
  tempBME280 = bme.readTemperature();
  humBME280 = bme.readHumidity();
  presBME280 = bme.readPressure() / 100.0F;
#ifdef DEBUG
  Serial.print("BME280 temperature: ");
  Serial.print(tempBME280);
  Serial.println(" °C");
  Serial.print("BME280 humidity: ");
  Serial.print(humBME280);
  Serial.println("% rH");
  Serial.print("BME280 pressure: ");
  Serial.print(presBME280);
  Serial.println(" hPa");
#endif
}

// Function to calculate sleep time and check if we need to send data
bool sleepLogic()
{
  currentEpoch = rtc.getEpoch();

  if (currentEpoch < wakeUpEpoch)
  {
    timeToSleep = (wakeUpEpoch - currentEpoch) * uS_TO_S_FACTOR;
#ifdef DEBUG
    Serial.println("ESP will sleep for: " + String(timeToSleep / 1000000) + " seconds");
#endif
  }
  else
  {
    timeToSleep = TIME_TO_SLEEP * uS_TO_S_FACTOR;
    wakeUpEpoch = (currentEpoch + TIME_TO_SLEEP);
#ifdef DEBUG
    Serial.println("ESP will sleep for: " + String(timeToSleep / 1000000) + " seconds");
#endif
  }

  esp_sleep_enable_ext0_wakeup(GPIO_NUM_4, 1);
  esp_sleep_enable_timer_wakeup(timeToSleep);

  if (esp_sleep_get_wakeup_cause() == 2)
  { // 2=ext0, 4=timer
#ifdef DEBUG
    Serial.println("Wake = 2; rain sensor");
#endif
    return true;
  }
  else
  {
#ifdef DEBUG
    Serial.println("Wake = 4; timer");
#endif
    return false;
  }
}

// Function to check if module is registered to network
void checkConnection()
{
  if (quectel.getRegistrationStatus(5)) // Check if nb module is registred to network
  {
#ifdef DEBUG
    Serial.println("Module is registered to network");
#endif
  }
  else
  {
    if (connectionTries < 3)
    {
      connectionTries++;
#ifdef DEBUG
      Serial.println("Module is not registered to network, trying again after deepsleep");
#endif
      delay(10);
      esp_deep_sleep_start();
    }
    else
    {
      connectionTries = 0;
#ifdef DEBUG
      Serial.println("Module is not registered to network, trying again after UE functionality reset");
#endif
      quectel.setUEFun(0);
      delay(1000);
      quectel.setUEFun(1);
      delay(5000);
      checkConnection();
    }
  }
}

// Function to transmit data to server
void transmitData()
{
  quectel.begin(&SERIAL_PORT);
  delay(100);
  quectel.setDeepSleep(0); // Disable deep sleep
  delay(1000);
  checkConnection();
  delay(1000);
  quectel.getData(); // Init struct with engineering data
  delay(1000);
  quectel.openUDP(nbServer, nbPort);
  delay(1000);
  float t1 = round2(temp1);
  float t2 = round2(temp2);
  float tSHT45 = round2(tempSHT45);
  float hSHT45 = round2(humSHT45);
  float tBME280 = round2(tempBME280);
  float hBME280 = round2(humBME280);
  float pBME280 = round2(presBME280);
  float l = round2(light);
  float v = round2(Voltage / 1000);
  char *msg;
  msg = (char *)malloc(255);
  sprintf(msg, "%d,%d,%d,%d,%d,%.2f,%.2f,%.2f,%.2f,%.2f,%.2f,%.2f,%.2f,%.2f,%d", DEVICE_ADDRESS, quectel.engineeringData.RSRP, 
          quectel.engineeringData.RSRQ, quectel.engineeringData.RSSI, quectel.engineeringData.SINR, t1, t2, tSHT45, hSHT45, tBME280, hBME280, pBME280, l, v, rainCount);
#ifdef DEBUG
  Serial.println(msg);
#endif
  quectel.sendDataUDPn(msg, strlen(msg), 1);
  free(msg);
  delay(1000);
  quectel.closeUDP();
  delay(300);
  quectel.setDeepSleep(1);
}

// Function called by interrupt (increment rainCount if called)
void callBack()
{
  if ((millis() - lastDebounceTime) > debounceDelay)
  {
    rainCount++;
    lastDebounceTime = millis();
#ifdef DEBUG
    Serial.println("Rain count incremented by interrupt to: " + String(rainCount));
#endif
  }
  else
  {
#ifdef DEBUG
    Serial.println("Interrupt ignored by debounce");
#endif
  }
}

// Main function
void setup()
{
#ifdef DEBUG
  Serial.begin(115200);
  delay(100);
#endif
  attachInterrupt(4, callBack, HIGH);

  if (sleepLogic())
  {
    rainCount++;
    lastDebounceTime = millis();
#ifdef DEBUG
    Serial.println("Rain count: " + String(rainCount));
    print_wakeup_reason();
    delay(1000);
    Serial.println("Going to sleep now");
#endif
    digitalWrite(EN, LOW);
    delay(5);
    esp_deep_sleep_start();
  }
  else
  {
    setupSensors();
    readSensors();
    transmitData();
    rainCount = 0;
#ifdef DEBUG
    Serial.println("Data send!");
    delay(1000);
    Serial.println("Going to sleep now");
#endif
    digitalWrite(EN, LOW);
    delay(5);
    esp_deep_sleep_start();
  }
}

// Loop function (not used)
void loop()
{
}

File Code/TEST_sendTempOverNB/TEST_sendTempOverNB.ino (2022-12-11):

#define DEBUG 

#include <ESP32Time.h>
#include <OneWire.h> 
#include <DallasTemperature.h>
#include <ArduinoJson.h>
#include "ATcommands.h"
#include "esp_adc_cal.h"
#include <BH1750.h>
#include <Wire.h>


#define uS_TO_S_FACTOR 1000000 //Conversion factor from uSeconds to minutes
#define TIME_TO_SLEEP  300         //Time ESP will go to sleep (in minutes)
#define MCU_RX 16 // Remember MCU RX connects to module TX and vice versa
#define MCU_TX 17
#define RST 19 // MCU pin to control module reset
#define PSM 18 // MCU pin to control module wake up pin (PSM-EINT_N)
#define TPIN 32 // DS18B20 pin
#define VOL_SENS 34 // Pin to measure voltage of battery
#define CAL 2 // Voltage devider ratio
#define EN 33 // Pin to power on sensors
#define NBdelay  1000   // Delay between two AT commands

RTC_DATA_ATTR int sendCount = 0;
RTC_DATA_ATTR ulong wakeUpEpoch = 0;
RTC_DATA_ATTR int rainCount = 0;

HardwareSerial *moduleSerial = &Serial2;

long lastMsg = 0;
char msg[50];
int value = 0;
String MQTTtopic = "Test/NB";

String JSONmessage;
  float temp1;
  float temp2;
  float light;
  float Voltage = 0.00;   // Voltage in mV

int volSens_Result = 0; // Raw value from ADC

//Sensors definitions
OneWire oneWire(TPIN); //OneWire
DallasTemperature oneWireTemp(&oneWire);
ESP32Time rtc;  
ATcommands module = ATcommands(RST, PSM, true);
BH1750 lightMeter(0x23);



int timeToSleep = 0;
ulong currentEpoch = 0;


void print_wakeup_reason(){
  esp_sleep_wakeup_cause_t wakeup_reason;
  wakeup_reason = esp_sleep_get_wakeup_cause();
  switch(wakeup_reason)
  {
    case ESP_SLEEP_WAKEUP_EXT0 : Serial.println("Wakeup caused by external signal using RTC_IO"); break;
    case ESP_SLEEP_WAKEUP_EXT1 : Serial.println("Wakeup caused by external signal using RTC_CNTL"); break;
    case ESP_SLEEP_WAKEUP_TIMER : Serial.println("Wakeup caused by timer"); break;
    case ESP_SLEEP_WAKEUP_TOUCHPAD : Serial.println("Wakeup caused by touchpad"); break;
    case ESP_SLEEP_WAKEUP_ULP : Serial.println("Wakeup caused by ULP program"); break;
    default : Serial.printf("Wakeup was not caused by deep sleep: %d\n",wakeup_reason); break;
  }
}

void setupSensors(){
    pinMode(EN, OUTPUT);
    digitalWrite(EN, HIGH);
    delay(100);

    Wire.begin (21, 22);
    oneWireTemp.begin(); 
    if (lightMeter.begin(BH1750::ONE_TIME_HIGH_RES_MODE_2)) {
      #ifdef DEBUG
      Serial.println(F("BH1750 Advanced begin"));
      #endif
    } else {
      #ifdef DEBUG
      Serial.println(F("Error initialising BH1750"));
      #endif
    }
}

void readSensors(){

  //First Temp sensor
  oneWireTemp.requestTemperatures();
  temp1 = oneWireTemp.getTempCByIndex(0); //Index 0 => first sensor on wire
  #ifdef DEBUG
  Serial.print("First DS18B temp: ");
  Serial.print(temp1);
  Serial.println(" °C");
  Serial.println();
  #endif

  //Second Temp sensor
  //oneWireTemp.requestTemperatures();
  temp2 = oneWireTemp.getTempCByIndex(1); //Index 1 => first sensor on wire
  #ifdef DEBUG
  Serial.print("Second DS18B temp: ");
  Serial.print(temp2);
  Serial.println(" °C");
  Serial.println();
  #endif

  //Voltage of battery
  volSens_Result = analogRead(VOL_SENS);
  Voltage = readADC_Cal(volSens_Result) * CAL;
  #ifdef DEBUG
  Serial.print(Voltage/1000.0); // Print Voltage (in V)
  Serial.println(" V");
  Serial.println(Voltage);      // Print Voltage (in mV)
  Serial.println(" mV");
  #endif
  

  //Light meter
  if (lightMeter.measurementReady()) {
    light = lightMeter.readLightLevel();
    #ifdef DEBUG
    Serial.print("Light: ");
    Serial.print(light);
    Serial.println(" lx");
    #endif
  }
}


uint32_t readADC_Cal(int ADC_Raw)
{
  esp_adc_cal_characteristics_t adc_chars;
  
  esp_adc_cal_characterize(ADC_UNIT_1, ADC_ATTEN_DB_11, ADC_WIDTH_BIT_12, 1100, &adc_chars);
  return(esp_adc_cal_raw_to_voltage(ADC_Raw, &adc_chars));
}

bool sleepLogic(){
  currentEpoch = rtc.getEpoch();

  if(currentEpoch < wakeUpEpoch){
    timeToSleep = (wakeUpEpoch - currentEpoch) * uS_TO_S_FACTOR;
    #ifdef DEBUG
    Serial.println("ESP will sleep for: " + String(timeToSleep/1000000) + " seconds");
    #endif
  } else {
    timeToSleep = TIME_TO_SLEEP * uS_TO_S_FACTOR;
    wakeUpEpoch = (currentEpoch + TIME_TO_SLEEP);
    #ifdef DEBUG
    Serial.println("ESP will sleep for: " + String(timeToSleep/1000000) + " seconds");
    #endif
  }

  esp_sleep_enable_ext0_wakeup(GPIO_NUM_4, 1);
  esp_sleep_enable_timer_wakeup(timeToSleep);

  if(esp_sleep_get_wakeup_cause() == 2){      // 2=ext0, 4=timer
    #ifdef DEBUG
    Serial.println("Wake = 2; pushbutton");
    #endif
    return true;
  } else {
    #ifdef DEBUG
    Serial.println("Wake = 4; timer");
    #endif
    return false;
  }
}

String prepMSG(){
  char msg[200];
  StaticJsonDocument<200> doc;
    doc["send"] = sendCount;
    doc["temp"] = temp1;
    doc["temp2"] = temp2;
    doc["vol"] = Voltage/1000;
    doc["light"] = light;
    doc["rain"] = rainCount;
  serializeJson(doc, JSONmessage);
  JSONmessage.toCharArray(msg, JSONmessage.length() + 1);
  
  #ifdef DEBUG
  Serial.print("Publish message: ");
  Serial.println(msg);
  Serial.print("Lenght of message: ");
  Serial.println(JSONmessage.length());
  Serial.println();
  delay(1000);
  #endif

  String MQTTsend = "AT+QMTPUB=0,0,0,0,";
  String result = MQTTsend + MQTTtopic + "," + strlen(msg) + "," + msg;
  
  return result;
}

void transmitData() {
  moduleSerial->begin(115200);
  module.begin(*moduleSerial);
  delay(100); 
  

  /*
  if(module.wakeUp(HIGH,10,"DEEPSLEEP")) Serial.println("Wake up succes!"); //Wakeup module
  delay(NBdelay);
  */
  if(module.sendCommand("AT", "DEEPSLEEP")) Serial.println("Set AT succes!");  //Turn off deepsleep
  delay(NBdelay);

  if(module.sendCommand("AT+QSCLK=0", "OK", 5000)) Serial.println("Set QSCLK=0 succes!");  //Turn off deepsleep
  delay(NBdelay);

  /*
  if(module.sendCommand("ATE0", "OK")) Serial.println("Set ATE0 succes!"); //Turn off local echo
  delay(NBdelay);
  */
  
  if(module.sendCommand("AT+CGPADDR?", "+CGPADDR: 0,")) Serial.println("Check IP succes!");  //Check if we have IP addr assigned
  delay(NBdelay);

  if(module.sendCommand("AT+QMTOPEN=0,89.221.217.87,1883", "+QMTOPEN: 0,0")) Serial.println("Set QMTOPEN succes!");  //Open MQTT connection
  delay(NBdelay);

  if(module.sendCommand("AT+QMTCONN=0,DevKit-0123456", "+QMTCONN: 0,0,0")) Serial.println("Set QMTCONN succes!");  //Connect to MQTT server with ID
  delay(NBdelay);
  
  char MQTTpub[200];
  String res = prepMSG();
  res.toCharArray(MQTTpub, res.length()+1);
  if(module.sendCommand(MQTTpub, "+QMTPUB: 0,0,0")) Serial.println("Send QMTPUB succes!");  //Publish msg
  delay(NBdelay);

  if(module.sendCommand("AT+QMTCLOSE=0", "+QMTCLOSE: 0,0")) Serial.println("Close QMTCLOSE succes!");  //Close MQTT connection
  delay(NBdelay);

  if(module.sendCommand("AT+QSCLK=1", "OK")) Serial.println("Set QSCLK=1 succes!");  //Turn on deepsleep
  delay(NBdelay);
}
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

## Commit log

2022-10-15 Added code to test deep sleep on ESP32
2022-10-15 Schematics of solar charger based on TP4056
    [Schematic.sch]
2022-10-16 Changed packeges to 0805
    [Schematic.sch]
2022-10-18 Schematic export to pdf and png
    [Schematic.sch]
2022-10-20 Temp sensors test code
2022-10-23 Board design
    [Schematic.brd, Schematic.sch]
2022-10-23 Added second bme280 sensor to test
2022-10-26 RTC example and test
    [DRILEGEND.CFG, Schematic.brd, Schematic.csv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]
2022-10-27 Added second DS18B and light sensor, removed ESP32 internal temp sensor as it isn't precise on low temps
2022-10-27 Made holes biggeer to be able to manufacture it
    [Schematic.brd]
2022-10-28 DW01A schematic, removed eagle.epf from gitignore
    [Schematic.brd, Schematic.sch]
2022-10-28 Main board schematics
    [Main board schematics.sch]
2022-10-30 Added uart programming interface
    [Main board schematics.sch]
2022-11-05 Battery managment board test code
2022-11-10 Created version of charger with JLC stock parts
    [PnP_Schematic_front.csv, Schematic.brd, Schematic.csv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]
2022-11-13 Using ESP32 internal RTC synced via NTP
2022-11-13 Added power circuits, connection to Quectel devkit
    [Main board schematics.sch, Schematic.brd, Schematic.sch]
2022-11-27 Board for semestral project done
    [Main board schematics - JLC version.brd, Main board schematics - JLC version.sch, Sample-BOM_JLCSMT.xlsx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]
2022-12-08 Test on V0.1 board
2022-12-09 Hardware test with I2C light sensor, temp, rain and battery measurment
2022-12-11 Added second temp sensor
2022-12-11 Repair mistakes: C2, flash pin on ESP, fan pinout
    [Main board schematics - JLC version.brd, Main board schematics - JLC version.sch, Main board schematics.sch]
2022-12-11 Pushed to Fusion
    [Main board schematics - JLC version.brd, Main board schematics - JLC version.sch]
2023-01-23 Added CSV data of tests
    [InfluxData_Temp_and_battery_test.csv, InfluxData_Temp_sensor_comparison.csv]
2023-02-01 Added Eagle project for future designs, now including wire connection and VEML7700 brakeout boards design
    [Brakeout board - wire connection.brd, Brakeout board - wire connection.sch]
2023-02-02 Separated wire connection board and VEM7700 brakeout board, to VEML7700 board added R and C acording to datasheet
    [Brakeout board - VEML7700.brd, Brakeout board - VEML7700.sch, Brakeout board - wire connection.brd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]
2023-02-05 Imported main board to project
    [Main board.sch]
2023-02-20 Final touches
    [Brakeout board - VEML7700.brd, Brakeout board - wire connection.brd, Brakeout board - wire connection.sch]
2023-02-26 pin definition correction
2023-02-26 Production files
    [Brakeout board - VEML7700.brd, Brakeout board - VEML7700.sch]
2023-02-26 Production data
    [Test board - MCP73871.brd, Test board - MCP73871.sch]
2023-02-26 I2C pull-up Rs added on switched source
    [Main board.sch]
2023-02-26 Work around Quectel BC660K NB-IoT module
    [Main board.sch]
2023-03-04 Work around Quectel BC660K-GL module
    [Main board.sch]
2023-03-18 Completed antena interface, power circuitry
    [Main board.sch]
2023-03-21 Main board .brd added
    [Main board.brd, Main board.sch]
2023-03-22 component placement
    [Main board.brd, Main board.sch]
2023-03-31 v2 board out in production
    [Main board.brd, Main board.sch]
2023-04-09 Added test sketch for VEML7700 lux sensor
2023-05-02 Debounce, VEML7700, init variables
    *Debounced callback for rain gauge input
    *Added code support for VEML7700 light sensor - replaced BH1750 sensor code
    *init variables to default states (helps parse data on backend)
    [NB_UDP.ino]
2023-05-12 Added DEVICE_ADDRESS to identify devices on server
2023-05-18 deleted unnecessary files
    [DRILEGEND.CFG, Main board schematics - JLC version.brd, Main board schematics - JLC version.sch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]
2023-05-18 Corrected mistakes
    [Main board.brd, Main board.sch]
2023-05-18 Upload to second board
2023-05-23 Reorder of files, added 3D models and NodeRED flow
    [25mm pole mount.stl, Bottom cover.f3d, Bottom cover.stl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]
2023-05-24 Added sample credentials file
2023-06-14 Moved voltage devider calibration to server
2023-06-14 remove build output
    [partitions.csv]
2023-11-21 RJ12 connectors wireup description
    [Main board.brd]
2023-11-21 Firmware with new added sensors (SHT45, BME280)
